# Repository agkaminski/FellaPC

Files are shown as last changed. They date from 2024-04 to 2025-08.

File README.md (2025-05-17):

# FellaPC

All-in-keyboard 6502 based PC with built-in BASIC interpreter.

Features:

- BASIC interpreter,
- 6502/65C02/W65C02S CPU @1.8432 MHz,
- 32 KiB of ROM, 24 KiB of static RAM,
- 640x480@60Hz VGA adapter with character generator (80x60 black and white text mode only),
- 6522 VIA for onboard control, I2C memory and user port,
- 2 UARTs (USB-C and RS-232),
- 68 or 63 button mechanical keyboard,
- edge connector expansion port,
- powered via USB-C port.

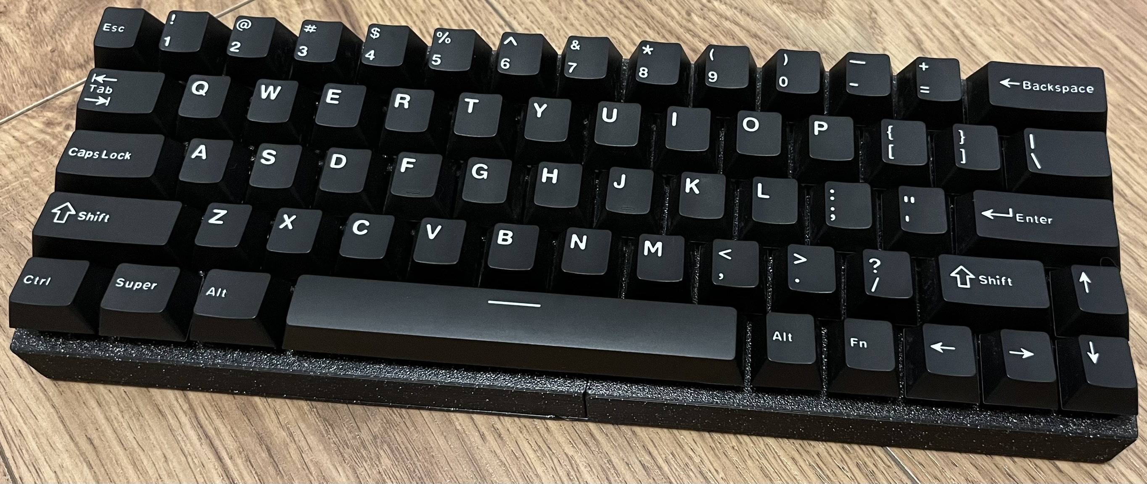
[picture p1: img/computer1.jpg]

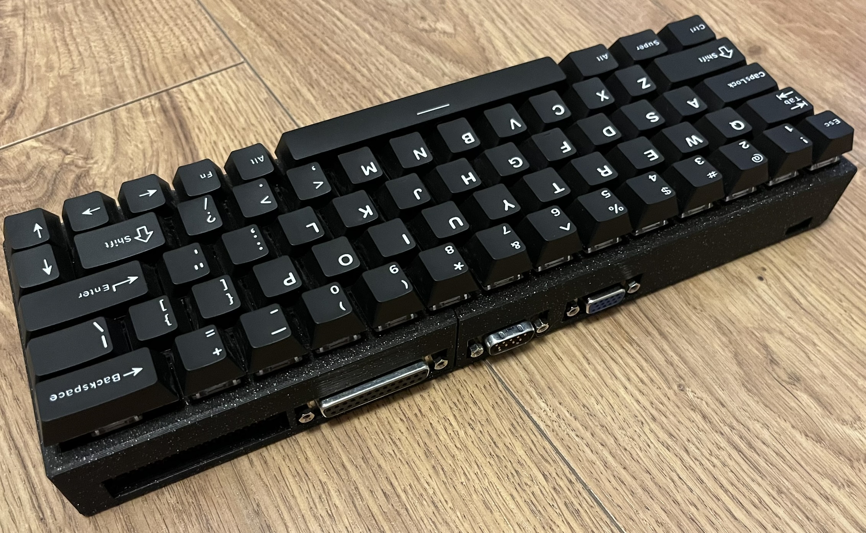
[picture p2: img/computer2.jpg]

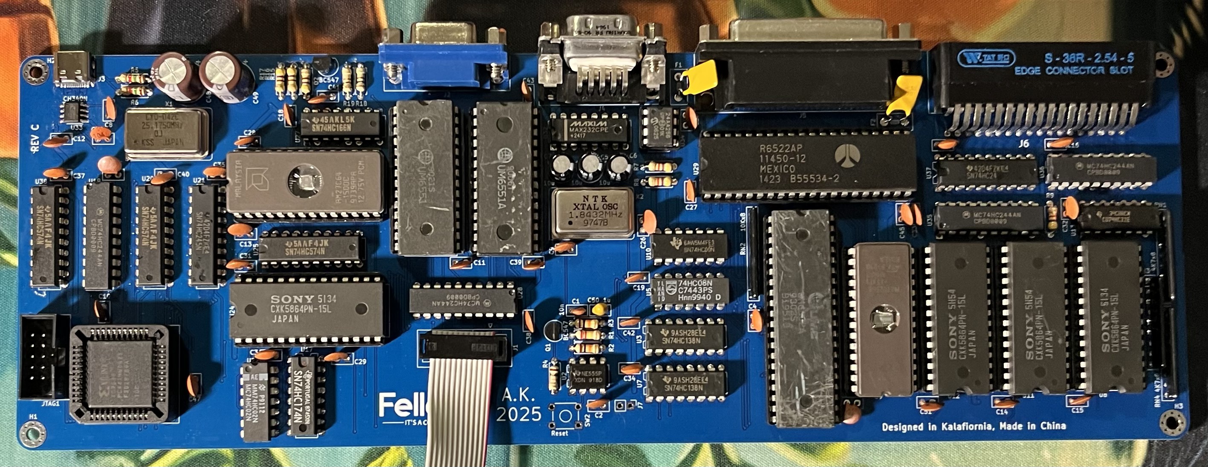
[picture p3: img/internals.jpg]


## Memory map

[Memory map](memmap.md)

## BASIC

FellaPC provides BASIC language subset (partially inspired by C64 BASIC).

### Program editing

Simple line editor is provided, code is entered line by line. To insert a new line or
overwrite existing line type in the line number followed by the code.

Example

```
10 FOR I = 0 TO 10
20 PRINT I
30 NEXT I
```

Let's say we want to change line number 20 to print a square of I insted. To do this
simply type in a new version of this line:

```
20 PRINT I*I
```

The program will be updated:

```
LIST

10 FOR I = 0 TO 10
20 PRINT I*I
30 NEXT I

Ready
```

### Commands

Following commands are supported:

#### PRINT

Print out to the screen.

Syntax examples:

```
PRINT "String"
PRINT "String", variable
PRINT "String"; variable
PRINT variable
PRINT var1, var2
```

#### INPUT

Prompt user for input, real numbers only.

Syntax examples:

```
INPUT var
INPUT "Prompt", var
```

#### FOR, TO, STEP, NEXT

Used for loops. Intelacing and infinite loop nesting are supported.

Syntax example:

```
10 FOR VAR=0 TO 10 STEP 2
20 PRINT I
30 NEXT I
```

Above loop will output:

```
0
2
4
6
8
```

#### GOTO

Jump to the line in the code.

Syntax example:

```
10 GOTO 30
20 PRINT "foo"
30 PRINT "bar"
```

Above code will output only `bar`, as `foo` has been skipped by `goto`.

#### GOSUB, RETURN

Similar to GOTO, but allows returning back from the destination of jump via `RETURN`.
Return address (line after `GOSUB`) is placed on the return stack. There is no limit
on the stack depth (apart from the computer memory capacity).

Syntax example:

```
10 GOSUB 200
20 PRINT "bar"
30 END
200 PRINT "foo"
210 RETURN
```

Folowing code will output:

```
foo
bar
```

#### IF, THEN, ELSE

Conditional execution.

Syntax example:

```
var = 5
10 IF var > 10 THEN 100 ELSE 200
100 PRINT "foo"
200 PRINT "bar"
```

Above code will only output `bar`, as var is not greater than 10.

#### CLEAR

Clear the screen and return cursor to the home position.

#### END

End program execution, return the interactive mode.

#### RUN

Starts execution of the program. Can be used in the interactive mode only.

#### LIST

Displays program. Can be used in the interactive mode only.

#### SAVE

Stores the program on the non-volatile memory. Can be used in the interactive mode only.

#### LOAD

Loads the program from the non-volatile memory. Can be used in the interactive mode only.

#### ABS()

Return absolute value.

Syntax example:

```
10 PRINT ABS(-5)
20 PRINT ABS(5)
```

This program will output:

```
5
5
```

#### FRE

Pseudo-variable. Return available BASIC memory in bytes.

#### INT()

Returns integer part of the real number.

Syntax example

```
PRINT INT(3.1412)
```

Will output `3`.

#### RND

Pseudo-variable. Return a random real number in the range of <0, 1).

#### PEEK(), POKE()

Functions that allow direct reading and modification of the computer memory.

Syntax examples:

```
PRINT PEEK(100)
```

Displays value of the memory at address 100.

```
POKE(100, 42)
```

Stores 42 at the address 100.

#### Operators

Following operators are supported:

```
( ) * + , - / ; < = > <= >= AND NOT OR
```

#### Variables

Variables are declared on the first use:

```
a = 5
var = 42
```

## Limitations

Applies to rev A, rev B:

All limitations in the firmware come from the limited size of the ROM space and
poor performance of the CC65 C compiler. 16 KB of program memory was thought to be
just enought to fit a full BASIC interpreter implementation. Alas, CC65 does not optimize
almost at all for the code size. 6502 is also infamous of not playing nice with the
C language. There was much struggle at the end of the development with the ROM space
running out - so some features were removed or abandoned and some functions has been
rewritten in assembled instead (which provides huge savings). It was deciced against
writing the BASIC interpreter itself in the assembler, in hope to reuse it in the future
project, with its portability in mind. Writing the whole firmware in assembler would also
prolong the project and more it difficult to maintain.

Due to above concerns, following hardware features are not handled by the firmware:

- both UARTs,
- 6522 VIA (apart from I2C and VGA ROM selection),
- interrupts (only NMI/VBLANK is handled).

Although these features can still be used by PEEK and POKE keywords of BASIC.

Visual glitches are expected on the VGA output when the VRAM is being modified. CPU is
too slow and DRAM refresh takes too long to be able to perfom any operation during
VBLANK.

## PCB

FellaPC rev C SBC PCB and keyboard PCB are a 2-layer design.

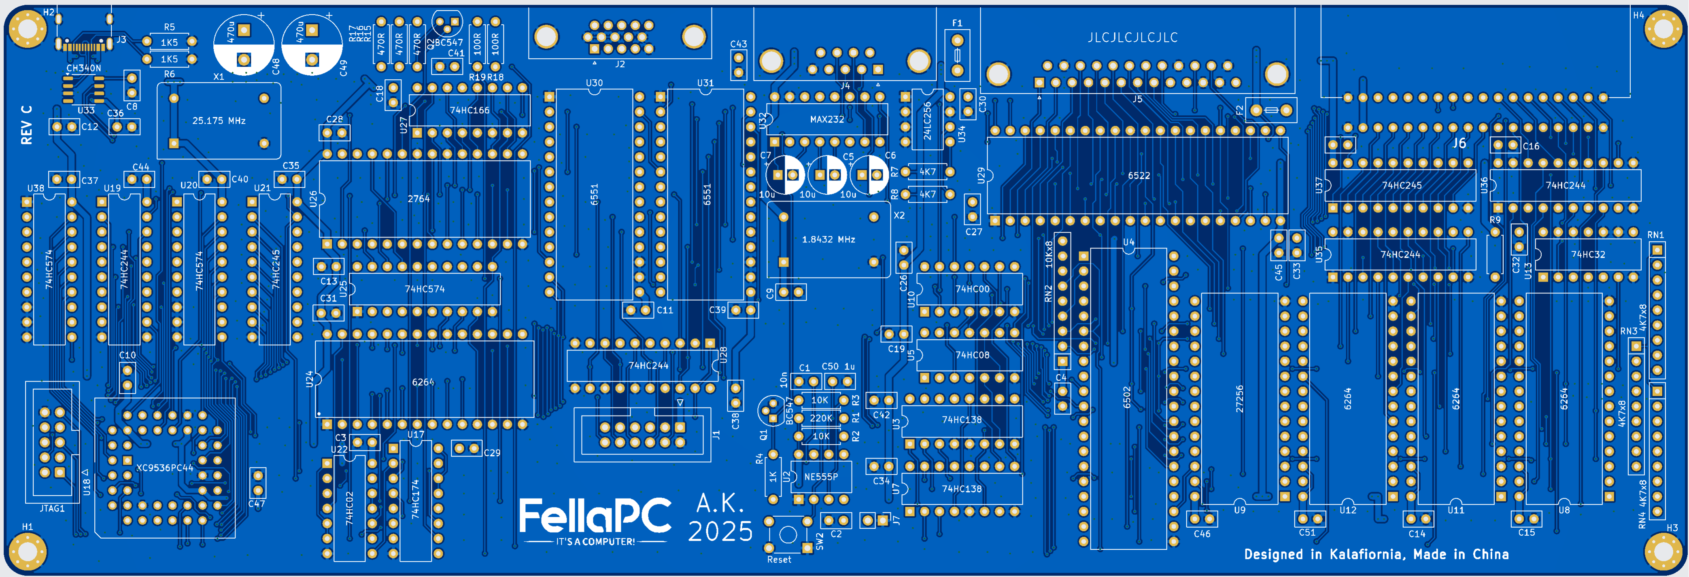
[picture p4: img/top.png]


## Case

Case is provided as STL files that are designed for the FDM 3D priting. There are
three parts:

- keyboard,
- main body,
- bottom panel.

All parts are too big to be printed in one piece on most 3D printers, so cutting
the model during slicing and glueing back together after printing might be needed.
Threaded inserts have to be embedded in the plastic.

Hardware needed:

- threaded inserts:
 - M3 4x5 mm 9 pieces,
 - M3 4x4 mm 4 pieces,
- bolts:
 - M3x4 or M3x5 for keyboard and SCB 8 pieces,
 - M3x25 for main body 5 pieces.

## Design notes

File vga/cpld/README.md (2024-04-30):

# CPLD - VGA timing generator and position counter

Target: XC9536, any speed, **not** XL version

## Pinout

| Pin | Type | Name |
|-----|---|---|
| 1 | I/O | vsync |
| 2 | I/O | hsync |
| 3 | I/O | blank |
| 4 | I/O | shload_n  |
| 5 | I/O/GCK1 | pclk |
| 6 | I/O/GCK2 | TIE |
| 7 | I/O/GCK3 | TIE |
| 8 | I/O | col<9> |
| 9 | I/O | col<8> |
| 10  | GND | GND |
| 11  | I/O | col<7> |
| 12  | I/O | col<6> |
| 13  | I/O | col<5> |
| 14  | I/O | col<4> |
| 15  | TDI | TDI |
| 16  | TMS | TMS |
| 17  | TCK | TCK |
| 18  | I/O | col<3> |
| 19  | I/O | vblank_n  |
| 20  | I/O | scroll<0> |
| 21  | VCCINT | VCC |
| 22  | I/O | scroll<1> |
| 23  | GND | GND |
| 24  | I/O | scroll<4> |
| 25  | I/O | row<8> |
| 26  | I/O | row<7> |
| 27  | I/O | row<6> |
| 28  | I/O | row<5> |
| 29  | I/O | row<4> |
| 30  | TDO | TDO |
| 31  | GND | GND |
| 32  | VCCIO | VCC |
| 33  | I/O | row<3> |
| 34  | I/O | row<2> |
| 35  | I/O | row<1> |
| 36  | I/O | row<0> |
| 37  | I/O | oe_n |
| 38  | I/O | scroll<5> |
| 39  | I/O/GSR  | rst_n |
| 40  | I/O/GTS2 | TIE |
| 41  | VCCINT | VCC |
| 42  | I/O/GTS1 | TIE |
| 43  | I/O | scroll<2> |
| 44  | I/O | scroll<3> |

## vga.v

Implementation

## vga.ucf

Pinout constraints (ISE 14.7)

## vga.jed

Bitstream ready to upload

## tb.v

Sorry excuse for a testbench

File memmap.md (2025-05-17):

# Memory map

| Start  | End | Description |
|---|---|---|
| 0x0000 | 0x5FFF | RAM |
| 0x6000 | 0x7FFF | I/O |
| 0x8000 | 0xFFFF | ROM |

# I/O register map

| Address | Peripheral | Register  | Description |
|---|---|---|---|
| 0x6000  | VGA | VDATA | VGA data (128 registers) |
| 0x6400  | VGA | VRA | VGA row address |
| 0x6800  | VGA | VSCRL | VGA vertical scroll |
| 0x6C00  | Keyboard | COLx | Keyboard columns (0-15) |
| 0x7000  | User port  | ORB | Port B output register |
| 0x7001  | User port  | ORA | Port A output register |
| 0x7002  | User port  | DDRB | Port B direction register |
| 0x7003  | User port  | DDRA | Port A direction register |
| 0x7004  | User port  | T1(L/C)-L | Timer 1 low latch/counter |
| 0x7005  | User port  | T1C-H | Timer 1 high counter |
| 0x7006  | User port  | T1L-L | Timer 1 low latch |
| 0x7007  | User port  | T1L-H | Timer 1 high latch |
| 0x7008  | User port  | T2(L/C)-L | Timer 2 low latch/counter |
| 0x7009  | User port  | T2C-H | Timer 2 high counter |
| 0x700A  | User port  | SR | Shift register |
| 0x700B  | User port  | ACR | Auxiliary control register |
| 0x700C  | User port  | PCR | Peripheral control register  |
| 0x700D  | User port  | IFR | Interrupt flag register |
| 0x700E  | User port  | IER | Interrupt enable register |
| 0x700F  | User port  | ORA | Port A output register |
| 0x7400  | USB UART | TDR1/RDR1 | UART 1 data register |
| 0x7401  | USB UART | RST1/SR1  | UART 1 reset/status register |
| 0x7402  | USB UART | CMDR1 | UART 1 command register |
| 0x7403  | USB UART | CR1 | UART 1 control register |
| 0x7800  | RS232 | TDR2/RDR2 | UART 2 data register |
| 0x7801  | RS232 | RST2/SR2  | UART 2 reset/status register |
| 0x7802  | RS232 | CMDR2 | UART 2 command register |
| 0x7803  | RS232 | CR2 | UART 2 control register |

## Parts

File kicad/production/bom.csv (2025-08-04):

Designator | Footprint | Quantity | Value | LCSC Part #
C1 | C_Disc_D5.0mm_W2.5mm_P2.50mm | 1 | 10n
C10, C11, C12, C13, C14, C15, C16, C17, C18, C19, C2, C26, C27, C28, C29, C3, C30, C31, C32, C33, C34, C35, C36, C37, C38, C39, C4, C40, C41, C42, C43, C44, C45, C46, C47, C51, C8, C9 | C_Disc_D5.0mm_W2.5mm_P2.50mm | 38 | 100n
C48, C49 | CP_Radial_D10.0mm_P5.00mm | 2 | 470u
C5, C6, C7 | CP_Radial_D6.3mm_P2.50mm | 3 | 10u
C50 | C_Disc_D5.0mm_W2.5mm_P2.50mm | 1 | 1u
F1, F2 | Fuse_Littelfuse_395Series | 2 | Fuse
H1, H2, H3, H4 | MountingHole_3.2mm_M3_Pad_Via | 4 | MountingHole_Pad
J1 | IDC-Header_2x06_P2.54mm_Vertical | 1 | Conn_02x06_Odd_Even
J2 | DSUB-15-HD_Female_Horizontal_P2.29x1.98mm_EdgePinOffset3.03mm_Housed_MountingHolesOffset4.94mm | 1 | DE15_Receptacle_HighDensity_MountingHoles
J3 | USB_C_Receptacle_G-Switch_GT-USB-7010ASV | 1 | USB_C_Receptacle_USB2.0_14P
J4 | DSUB-9_Male_Horizontal_P2.77x2.84mm_EdgePinOffset7.70mm_Housed_MountingHolesOffset9.12mm | 1 | DE9_Plug_MountingHoles
J5 | DSUB-25_Socket_Horizontal_P2.77x2.84mm_EdgePinOffset7.70mm_Housed_MountingHolesOffset9.12mm | 1 | DB25_Receptacle_MountingHoles
J6 | EDGE_2x18 | 1 | Conn_02x18_Top_Bottom
J7 | PinHeader_1x02_P2.54mm_Vertical | 1 | Conn_01x02
JTAG1 | IDC-Header_2x05_P2.54mm_Vertical | 1 | Conn_02x05_Odd_Even
Q1, Q2 | TO-92 | 2 | BC547
R1 | R_Axial_DIN0207_L6.3mm_D2.5mm_P7.62mm_Horizontal | 1 | 220K
R15, R16, R17 | R_Axial_DIN0207_L6.3mm_D2.5mm_P7.62mm_Horizontal | 3 | 470R
R18, R19 | R_Axial_DIN0207_L6.3mm_D2.5mm_P7.62mm_Horizontal | 2 | 100R
R2, R3 | R_Axial_DIN0207_L6.3mm_D2.5mm_P7.62mm_Horizontal | 2 | 10K
R4 | R_Axial_DIN0207_L6.3mm_D2.5mm_P7.62mm_Horizontal | 1 | 1K
R5, R6 | R_Axial_DIN0207_L6.3mm_D2.5mm_P7.62mm_Horizontal | 2 | 1K5
R7, R8, R9 | R_Axial_DIN0207_L6.3mm_D2.5mm_P7.62mm_Horizontal | 3 | 4K7
RN1, RN3, RN4 | R_Array_SIP9 | 3 | 4K7x8
RN2 | R_Array_SIP9 | 1 | 10Kx8
SW2 | SW_TH_Tactile_Omron_B3F-10xx | 1 | Reset
U10 | DIP-14_W7.62mm | 1 | 74HC00
U11, U12, U24, U8 | DIP-28_W15.24mm | 4 | 6264
U13 | DIP-14_W7.62mm | 1 | 74HC32
U17 | DIP-16_W7.62mm | 1 | 74HC174
U18 | PLCC-44_THT-Socket | 1 | XC9536PC44
U19, U28, U35, U36 | DIP-20_W7.62mm | 4 | 74HC244
U2 | DIP-8_W7.62mm | 1 | NE555P
U20, U25, U38 | DIP-20_W7.62mm | 3 | 74HC574
U21, U37 | DIP-20_W7.62mm | 2 | 74HC245
U22 | DIP-14_W7.62mm | 1 | 74HC02
U26 | DIP-28_W15.24mm | 1 | 2764
U27 | DIP-16_W7.62mm | 1 | 74HC166
U29 | DIP-40_W15.24mm | 1 | 6522
U3, U7 | DIP-16_W7.62mm | 2 | 74HC138
U30, U31 | DIP-28_W15.24mm | 2 | 6551
U32 | DIP-16_W7.62mm | 1 | MAX232
U33 | SOP-8_3.9x4.9mm_P1.27mm | 1 | CH340N
U34 | DIP-8_W7.62mm | 1 | 24LC256
U4 | DIP-40_W15.24mm | 1 | W65C02SxP
U5 | DIP-14_W7.62mm | 1 | 74HC08
U9 | DIP-28_W15.24mm | 1 | 27256
X1 | Oscillator_DIP-14 | 1 | ACO-25.175MHz-A
X2 | Oscillator_DIP-14 | 1 | ACO-1.8432MHz-A

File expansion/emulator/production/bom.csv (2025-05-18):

Designator | Footprint | Quantity | Value | LCSC Part #
C1, C10, C11, C12, C14, C2, C3, C4, C5, C6, C8, C9 | C_Disc_D3.0mm_W1.6mm_P2.50mm | 12 | 100n
C15, C16 | C_Disc_D3.0mm_W1.6mm_P2.50mm | 2 | 22p
J2 | IDC-Header_2x03_P2.54mm_Vertical | 1 | Conn_02x03_Odd_Even
J3 | USB_C_Receptacle_GCT_USB4105-xx-A_16P_TopMnt_Horizontal | 1 | USB_C_Receptacle_USB2.0_14P
J5 | Expansion Connector | 1 | ~
R1, R4, R5 | R_Axial_DIN0207_L6.3mm_D2.5mm_P7.62mm_Horizontal | 3 | 10K
R2, R3 | R_Axial_DIN0207_L6.3mm_D2.5mm_P7.62mm_Horizontal | 2 | 1K5
U1 | DIP-28_W15.24mm | 1 | CY62256-70PC
U10, U2, U3, U4 | DIP-20_W7.62mm | 4 | 74HC244
U5 | DIP-14_W7.62mm | 1 | 74HC32
U6 | DIP-28_W7.62mm | 1 | ATmega8-16P
U7, U9 | DIP-20_W7.62mm | 2 | 74HC373
U8 | SOP-8_3.9x4.9mm_P1.27mm | 1 | CH340N
Y1 | Crystal_HC49-4H_Vertical | 1 | Crystal

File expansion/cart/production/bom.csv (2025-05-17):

Designator | Footprint | Quantity | Value | LCSC Part #
C1 | C_Disc_D3.4mm_W2.1mm_P2.50mm | 1 | 100n
J1 | PinHeader_1x02_P2.54mm_Vertical | 1 | Conn_01x02
U1 | CART_FELLA_38 | 1 | ~
U2 | DIP-28_W15.24mm | 1 | 27256

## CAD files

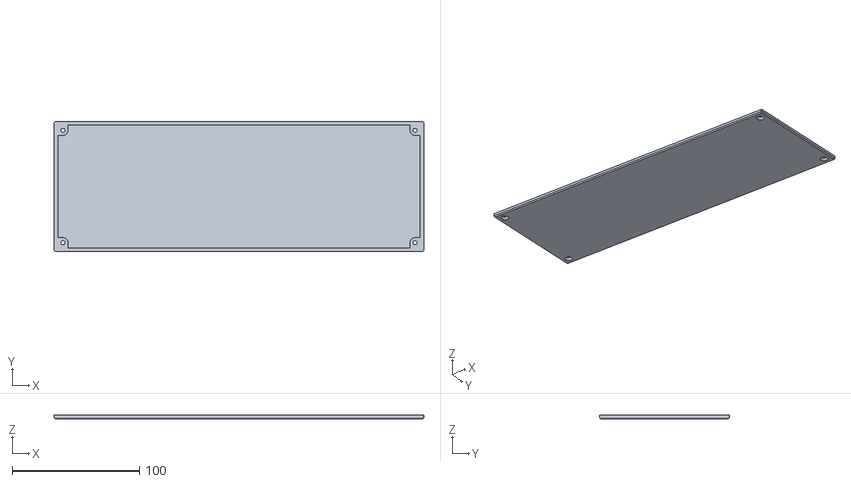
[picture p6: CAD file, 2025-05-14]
mechanical/mini-Bottom.stl
290.9 x 102.5 x 3.00

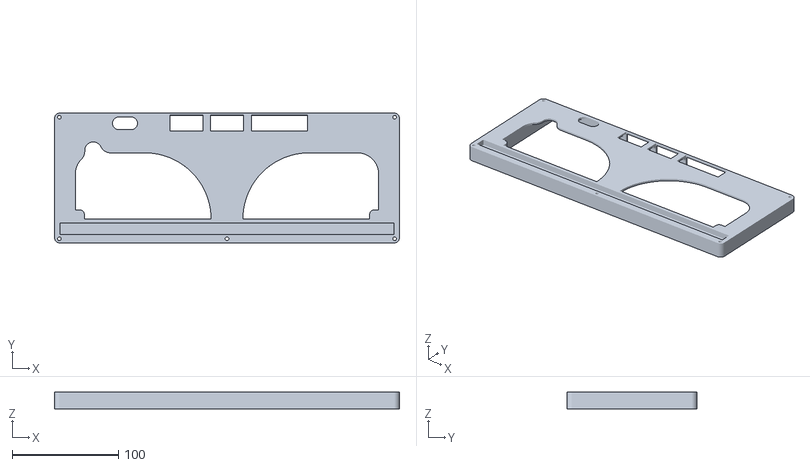
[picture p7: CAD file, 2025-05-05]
mechanical/body.stl
325.0 x 122.4 x 16.0

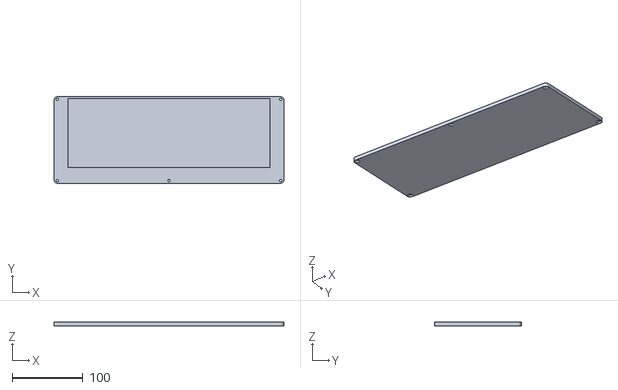
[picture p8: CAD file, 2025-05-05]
mechanical/bottom.stl
325.0 x 122.4 x 5.00

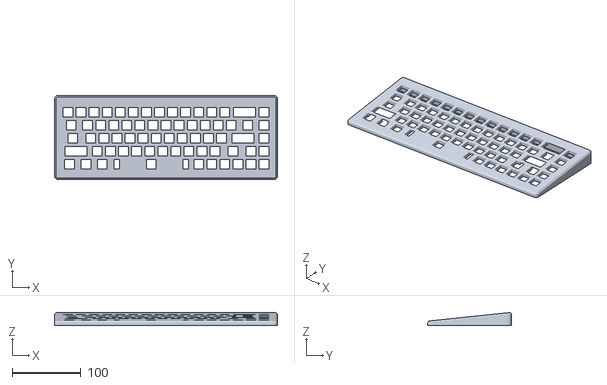
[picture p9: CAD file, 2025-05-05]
mechanical/keyboard.stl
325.0 x 122.4 x 18.9

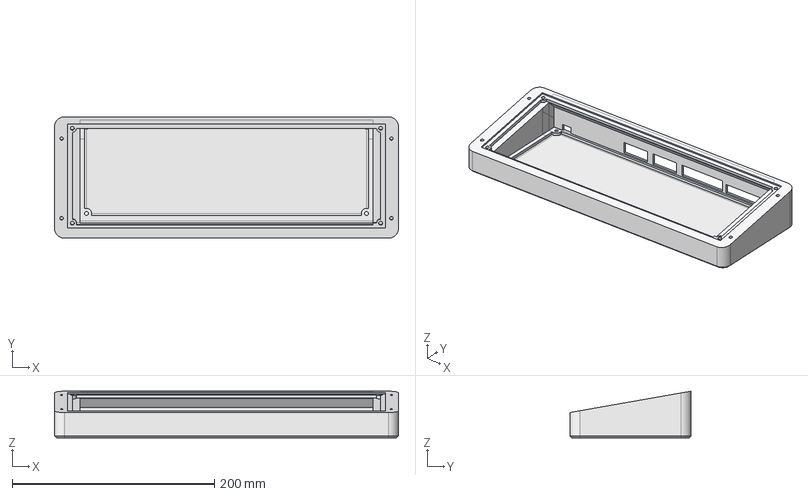
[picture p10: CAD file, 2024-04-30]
mechanical/case.FCStd
340.0 x 120.0 x 46.2 mm

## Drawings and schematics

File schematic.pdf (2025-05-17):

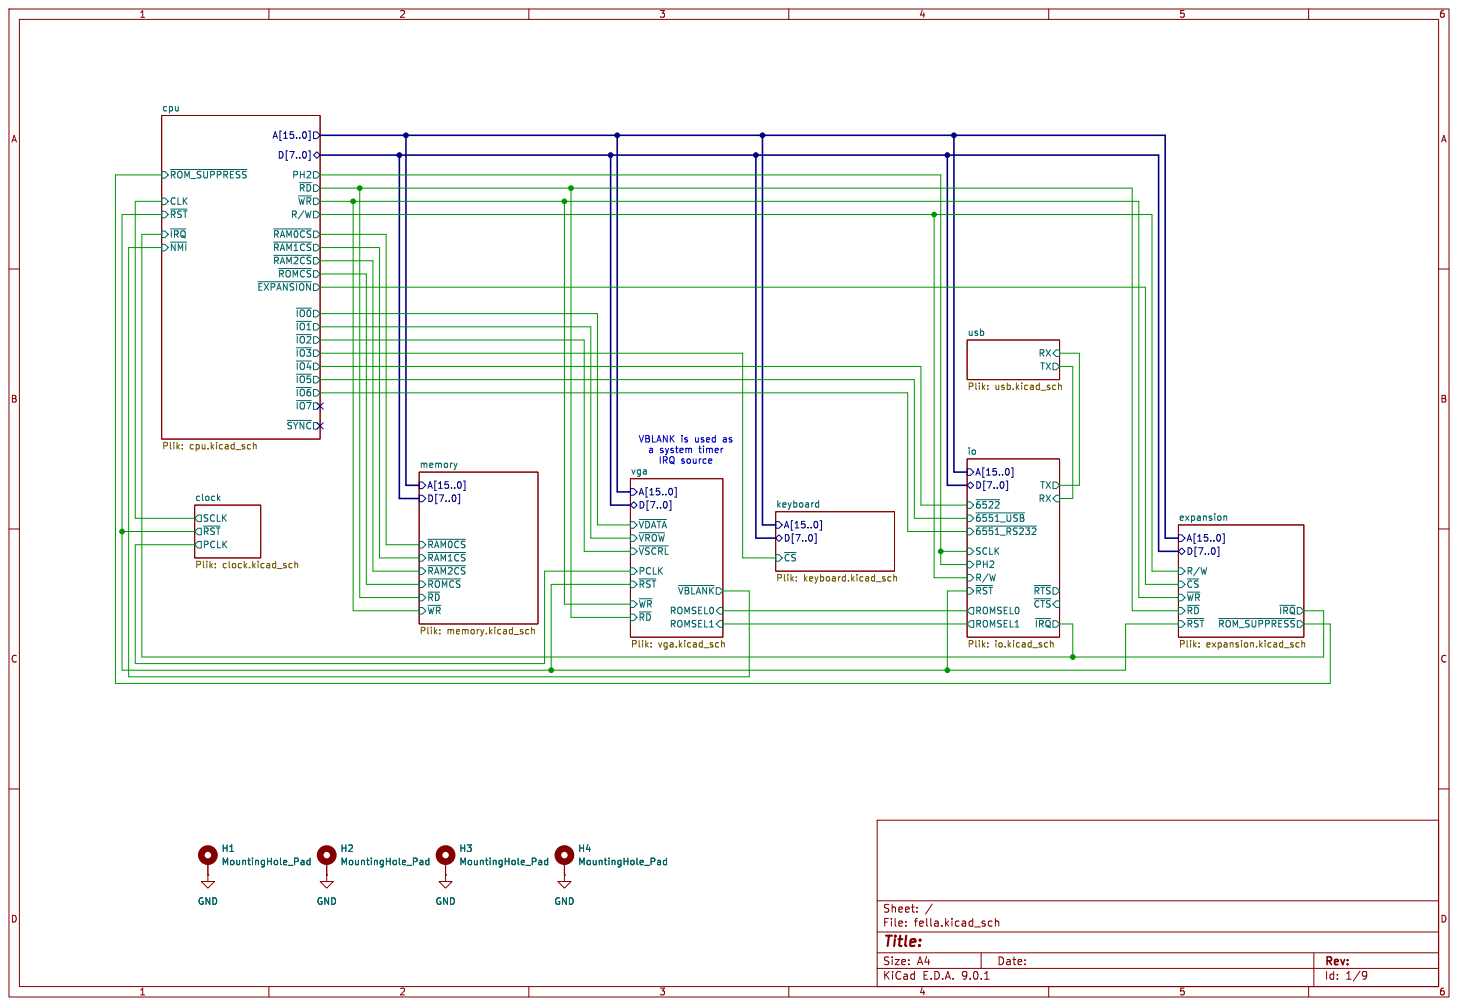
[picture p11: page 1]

usb Plik: usb.kicad_sch ~{RST} PCLK
~{VSCRL} vga Plik: vga.kicad_sch

~{ROMCS} memory Plik: memory.kicad_sch PCLK

keyboard Plik: keyboard.kicad_sch
Id: 1/9 Title: File: fella.kicad_sch Sheet: / A[15..0]

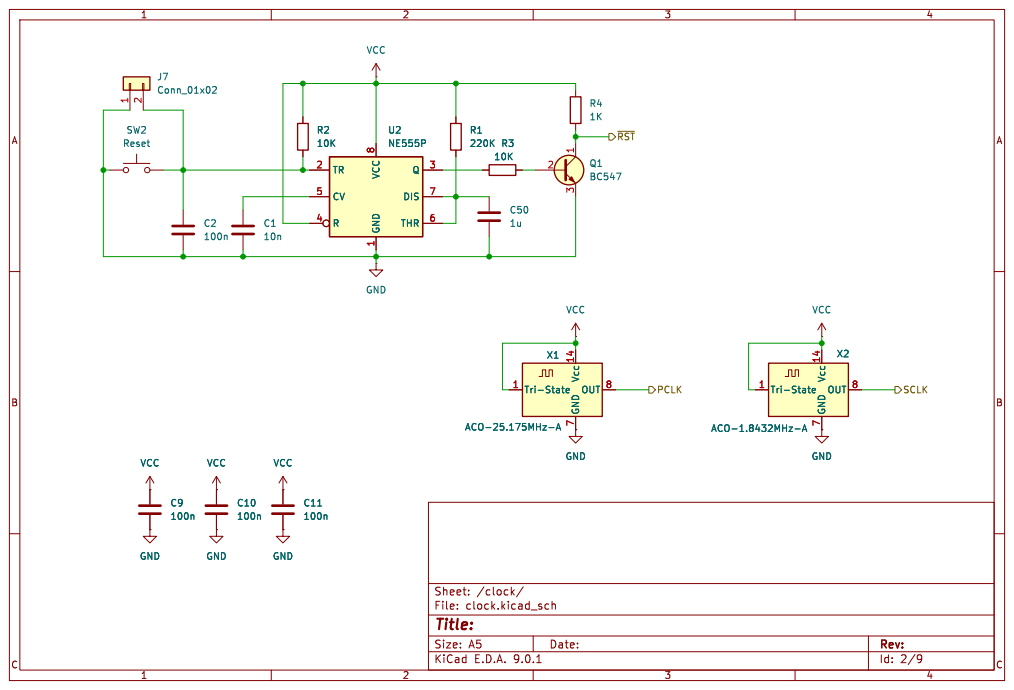
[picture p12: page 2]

Id: 2/9 Title: File: clock.kicad_sch Sheet: /clock/ VCC

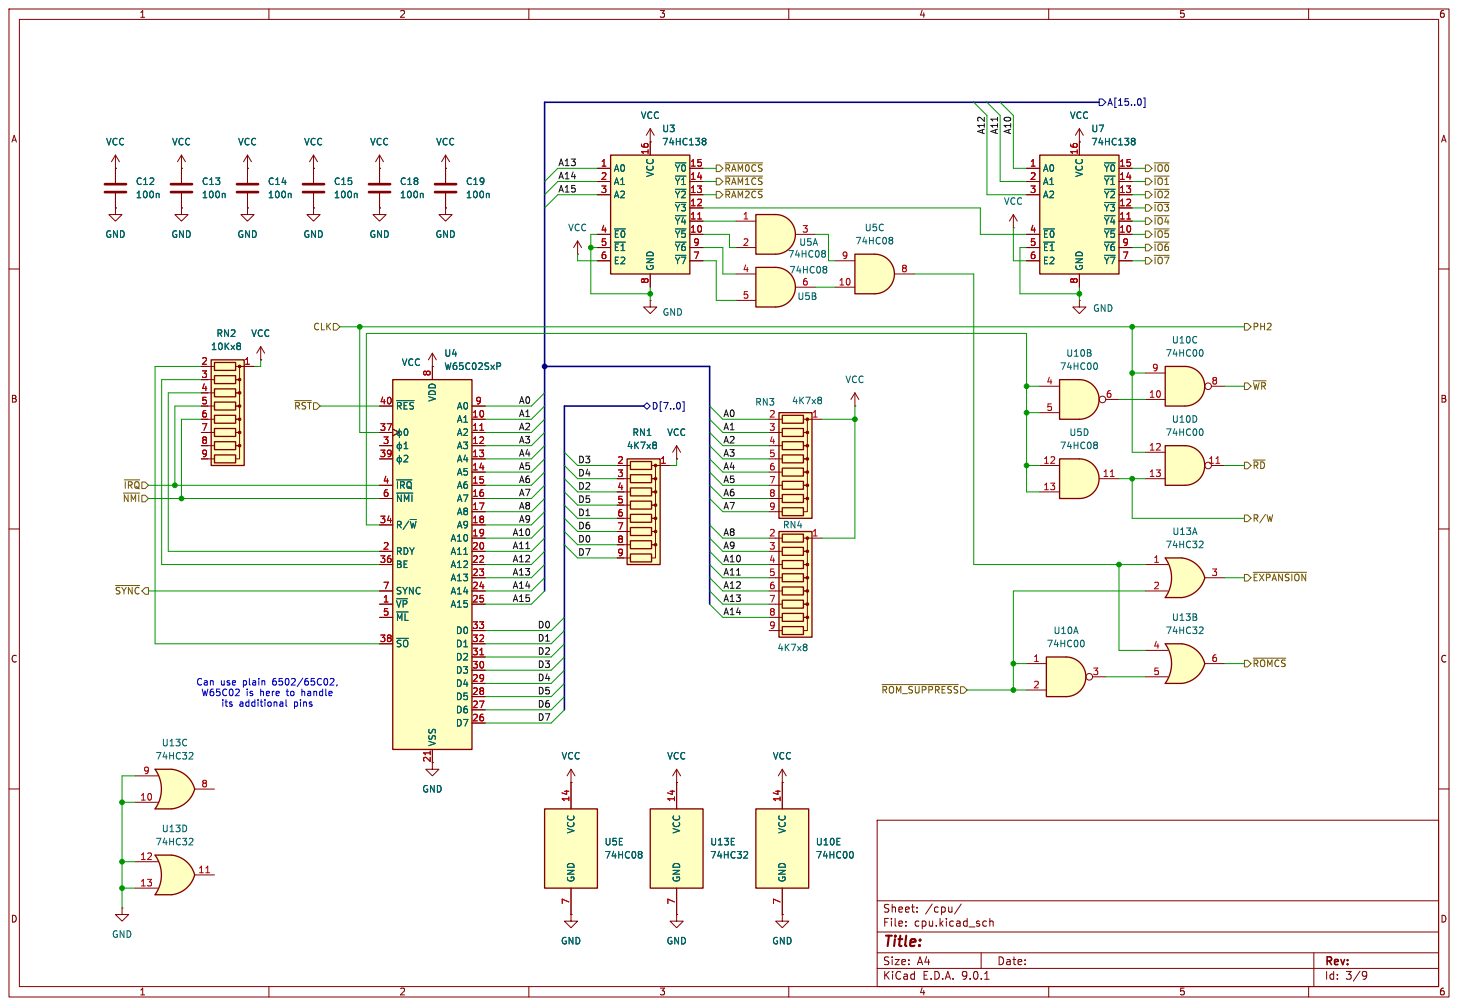
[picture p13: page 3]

A15 D5 Can use plain 6502/65C02, W65C02 is here to handle

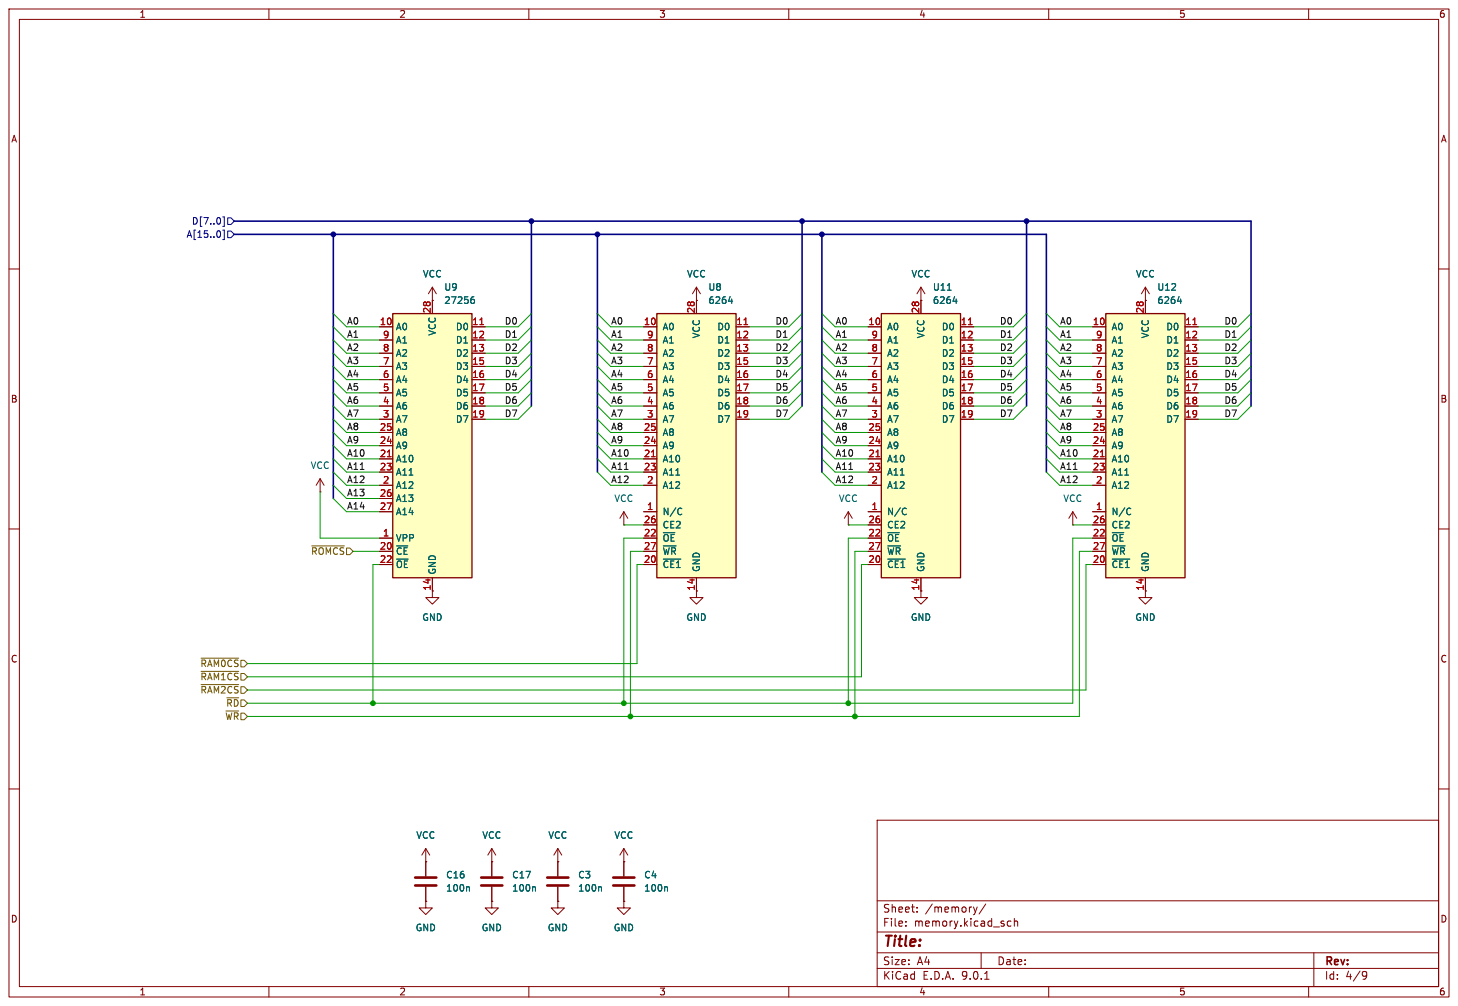
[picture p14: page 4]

Id: 4/9 Title: File: memory.kicad_sch Sheet: /memory/

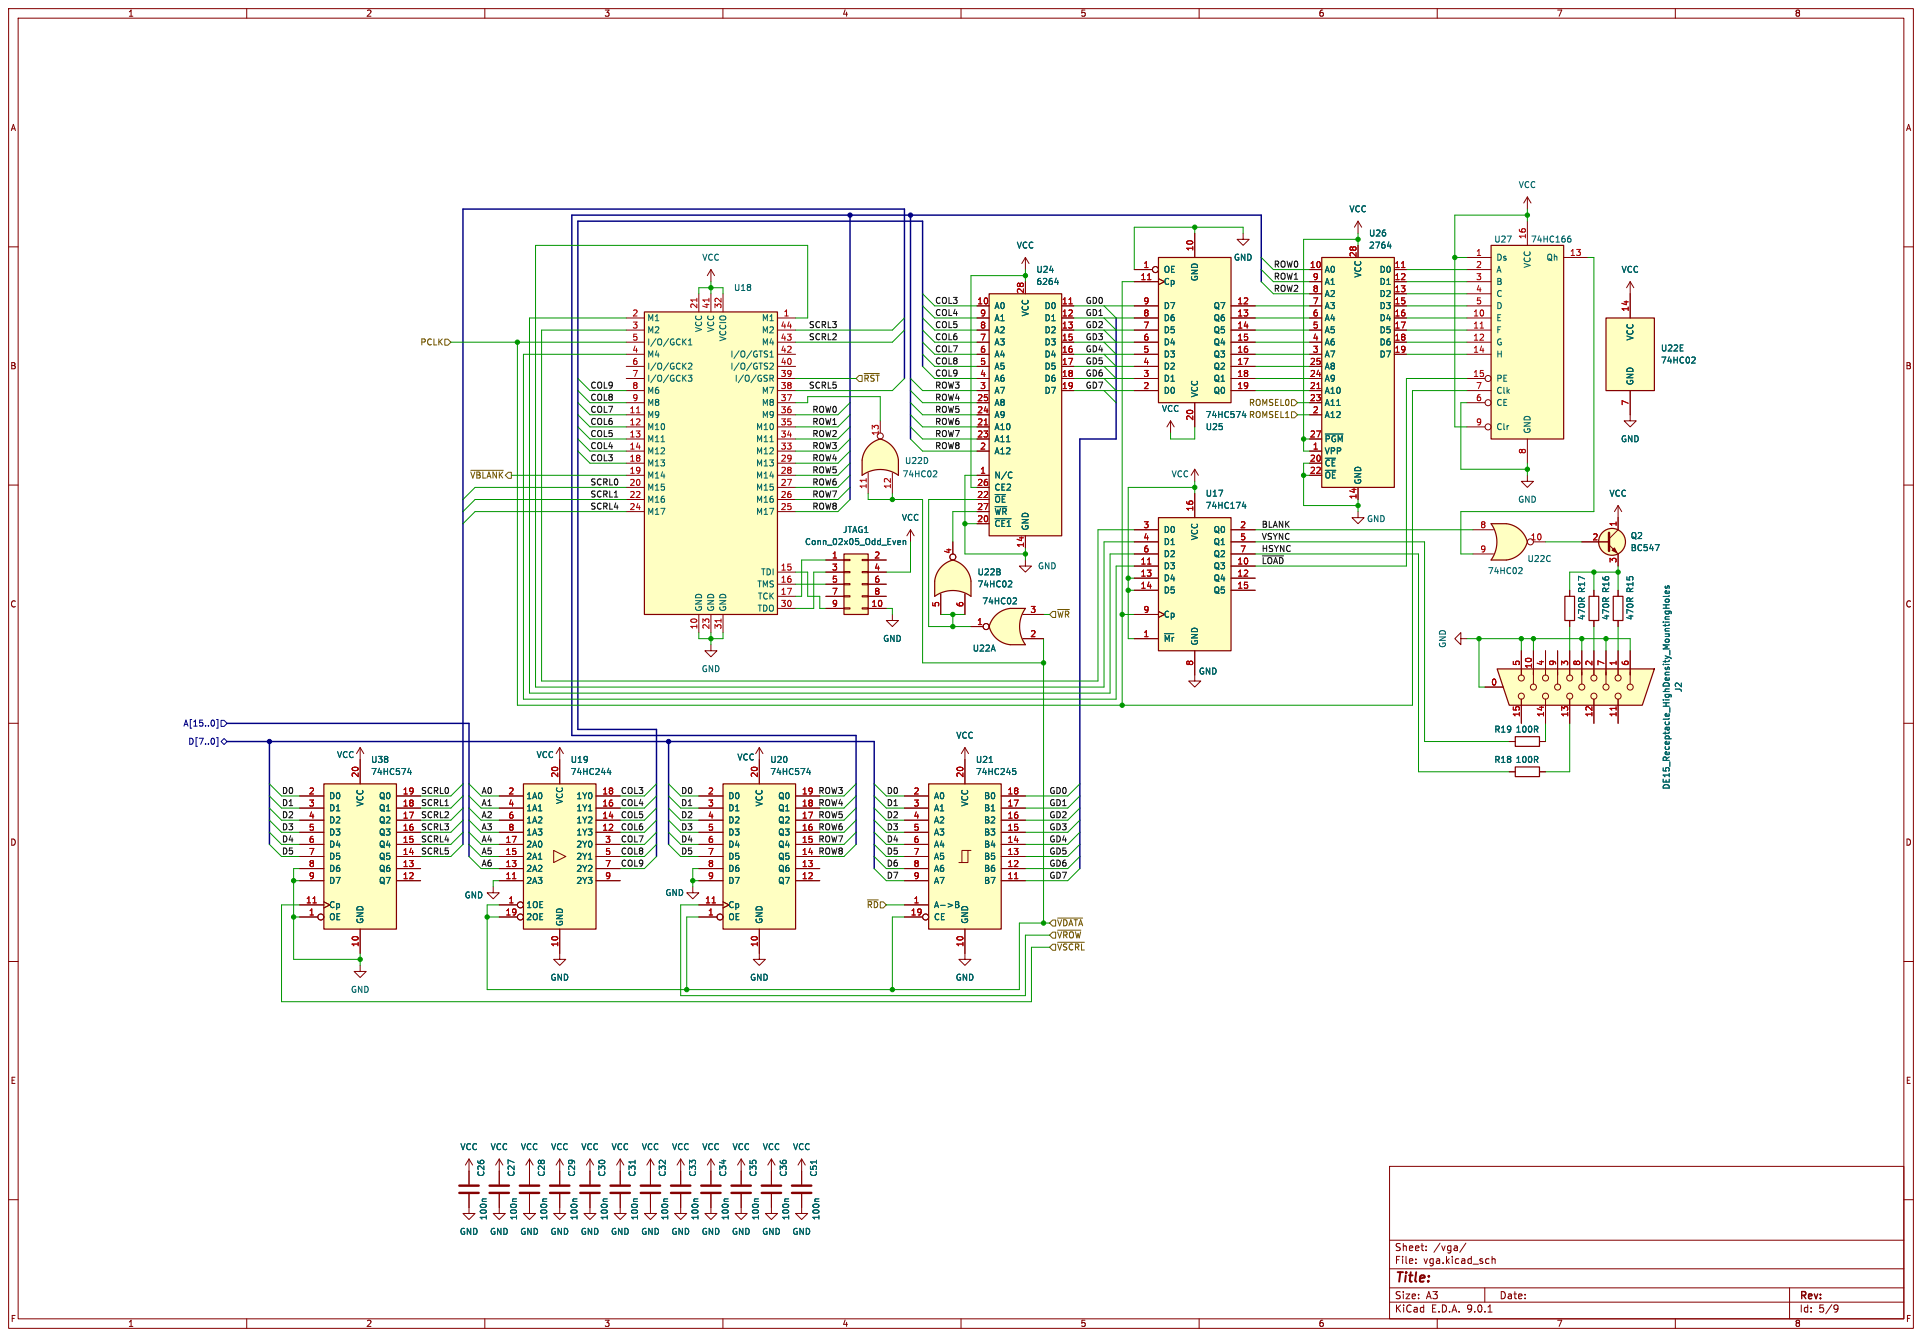
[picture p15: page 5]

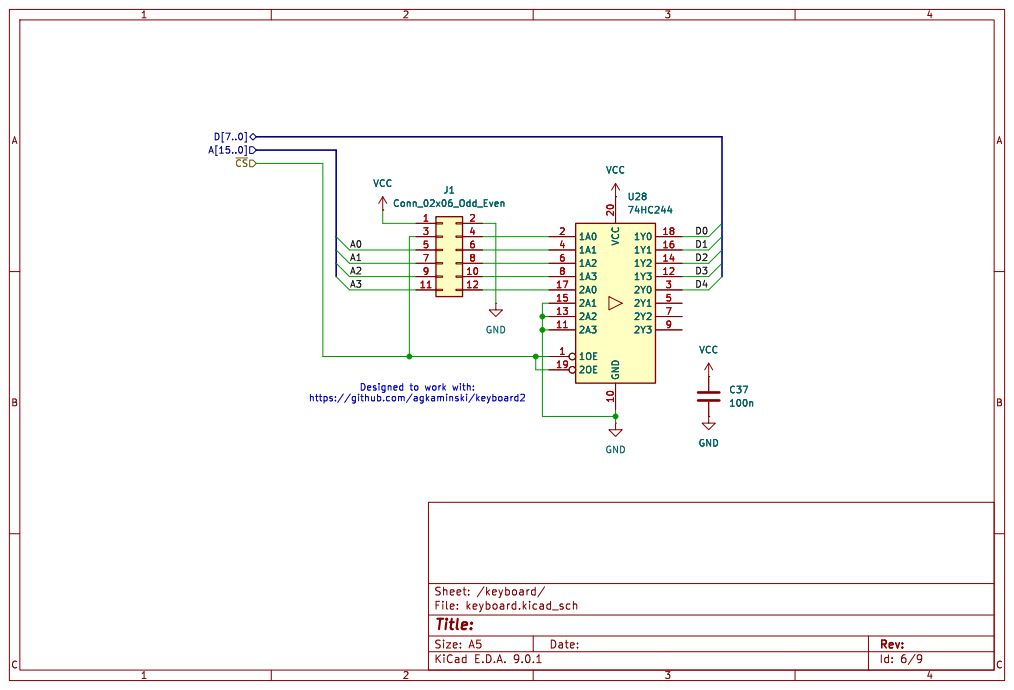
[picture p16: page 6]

10 10 | 1A3 8
12 | 2A0 17

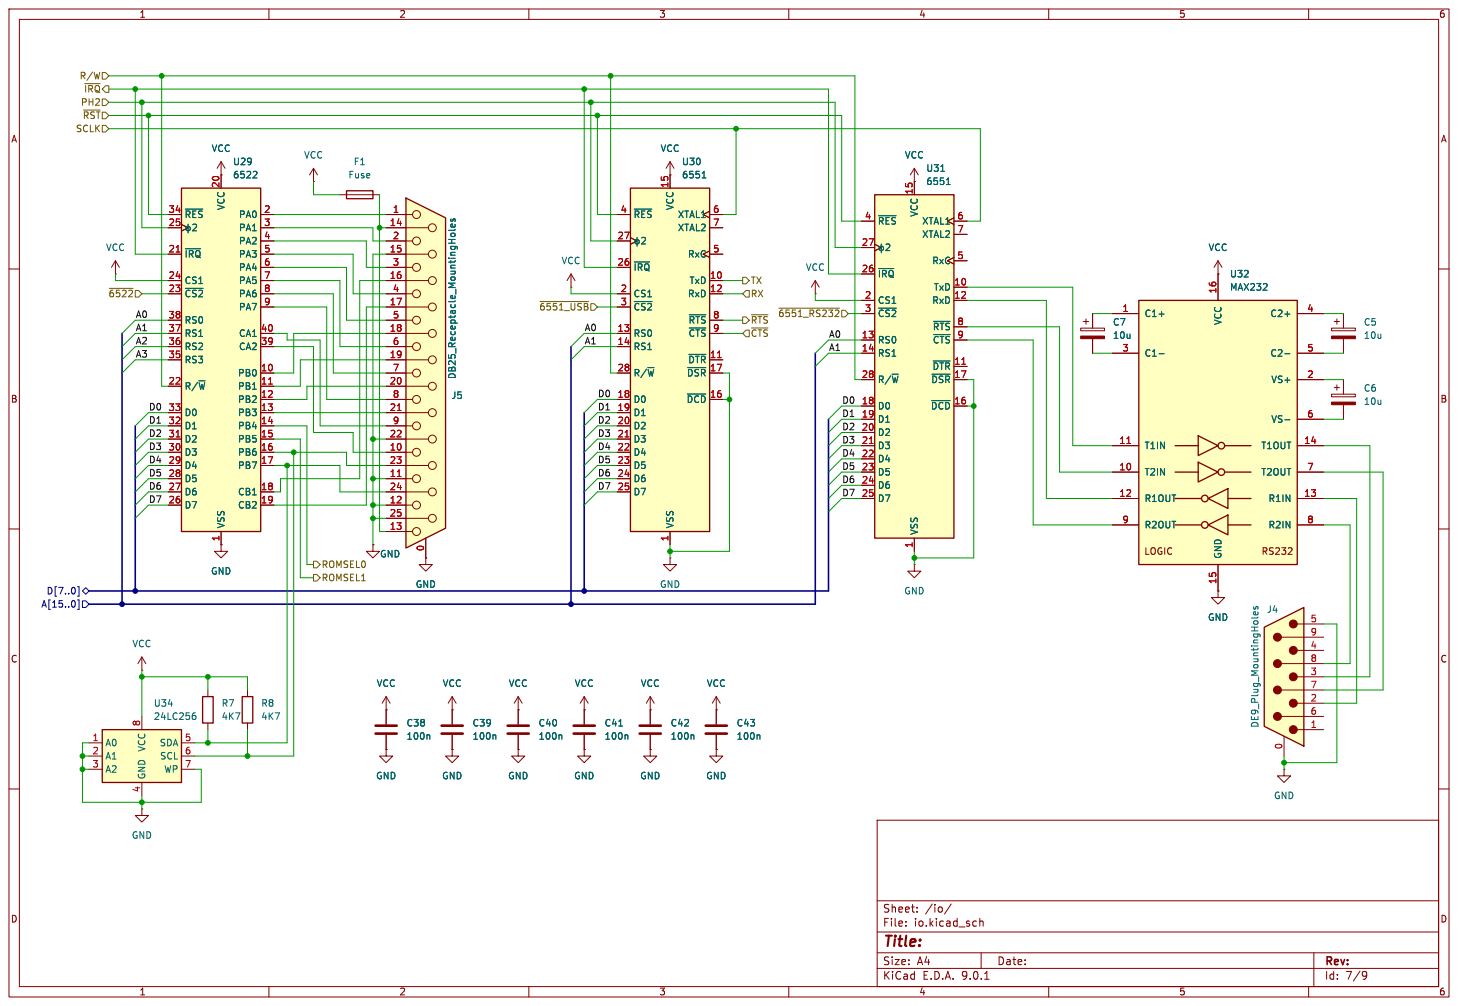
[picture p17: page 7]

Id: 7/9 Title: File: io.kicad_sch Sheet: /io/

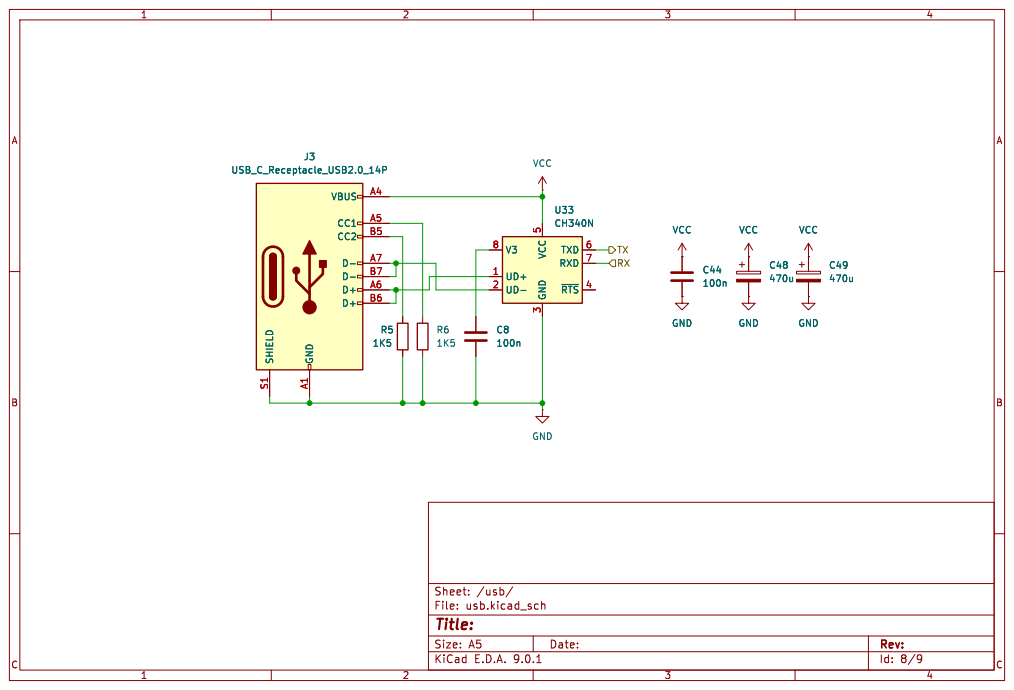
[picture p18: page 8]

3 TXD 6 RXD 7 ~{RTS}4 U33 CH340N GND

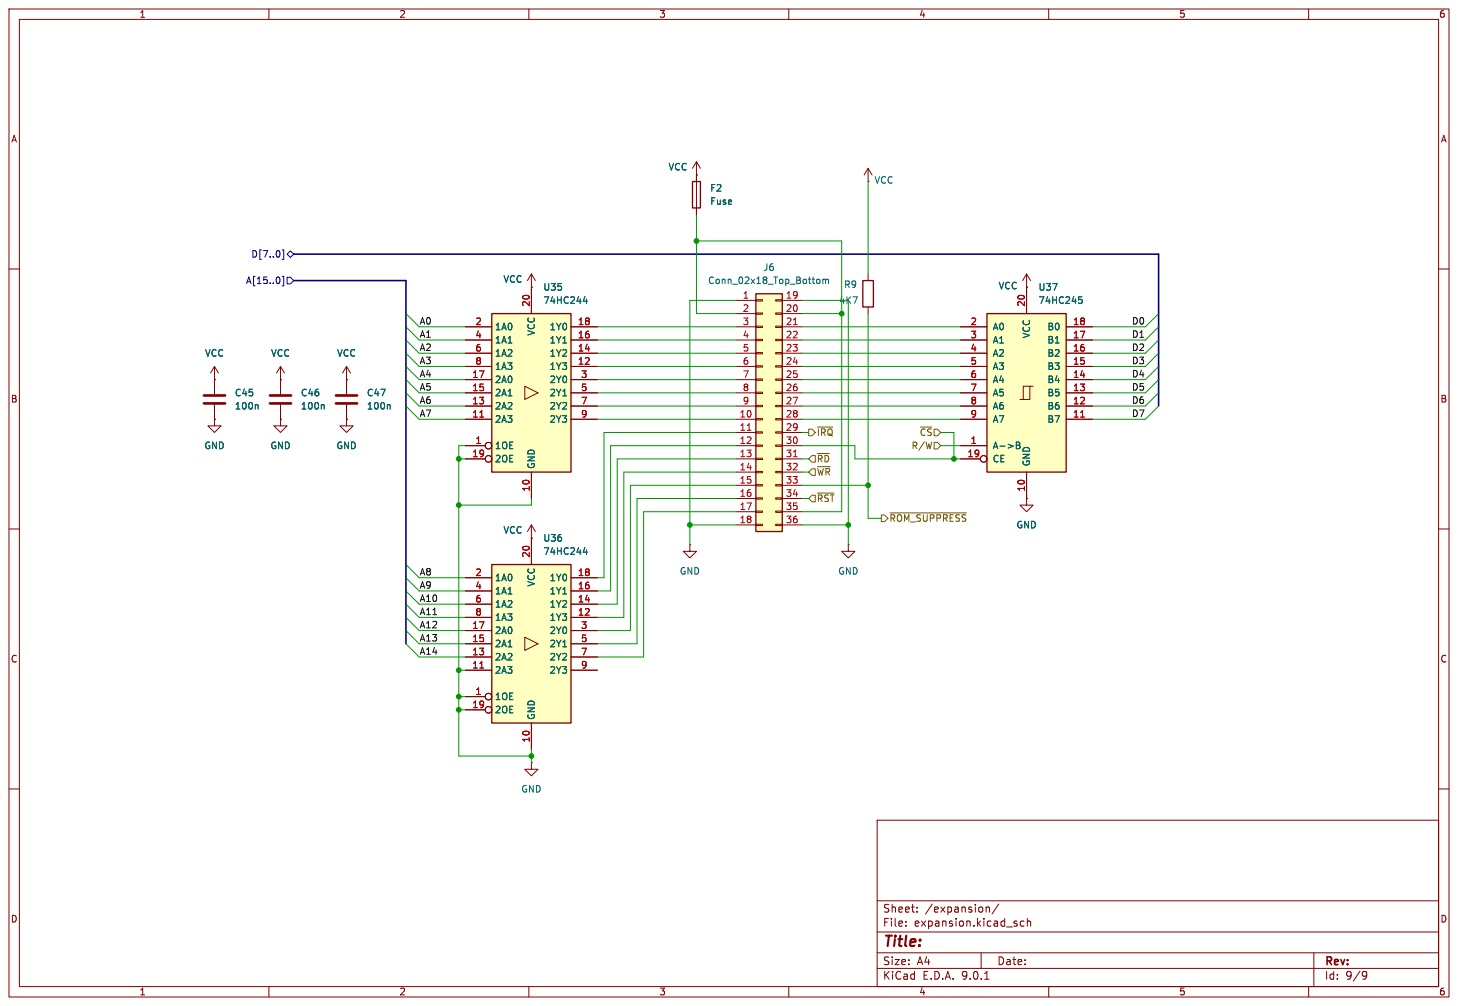
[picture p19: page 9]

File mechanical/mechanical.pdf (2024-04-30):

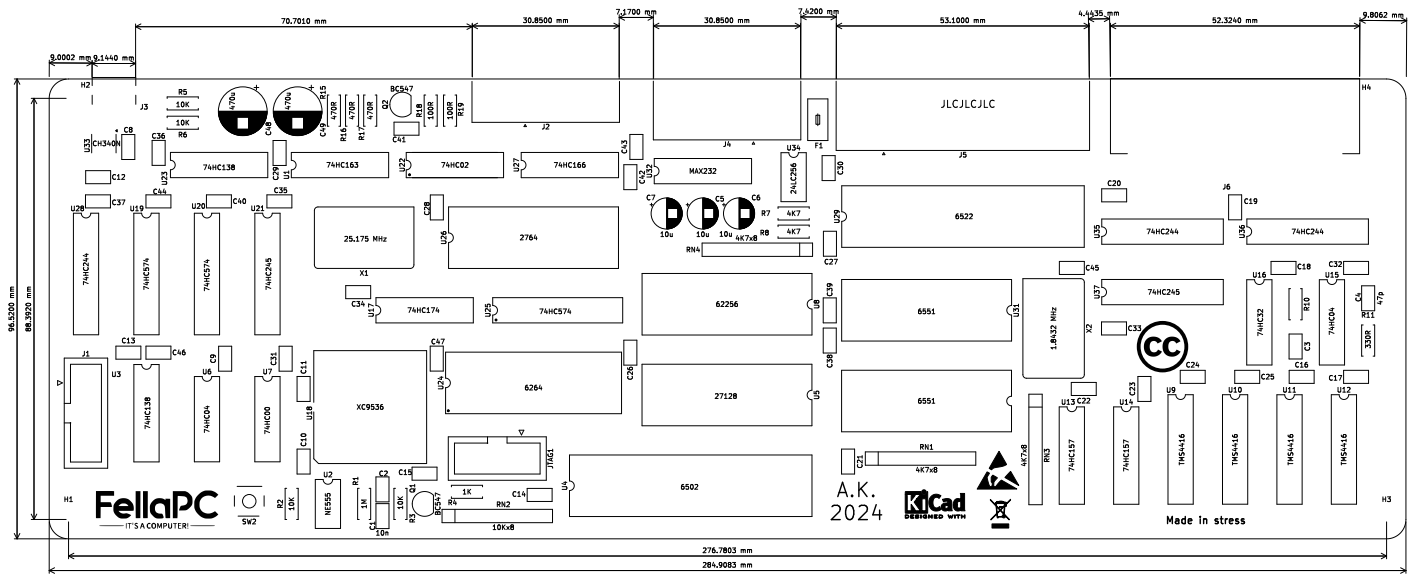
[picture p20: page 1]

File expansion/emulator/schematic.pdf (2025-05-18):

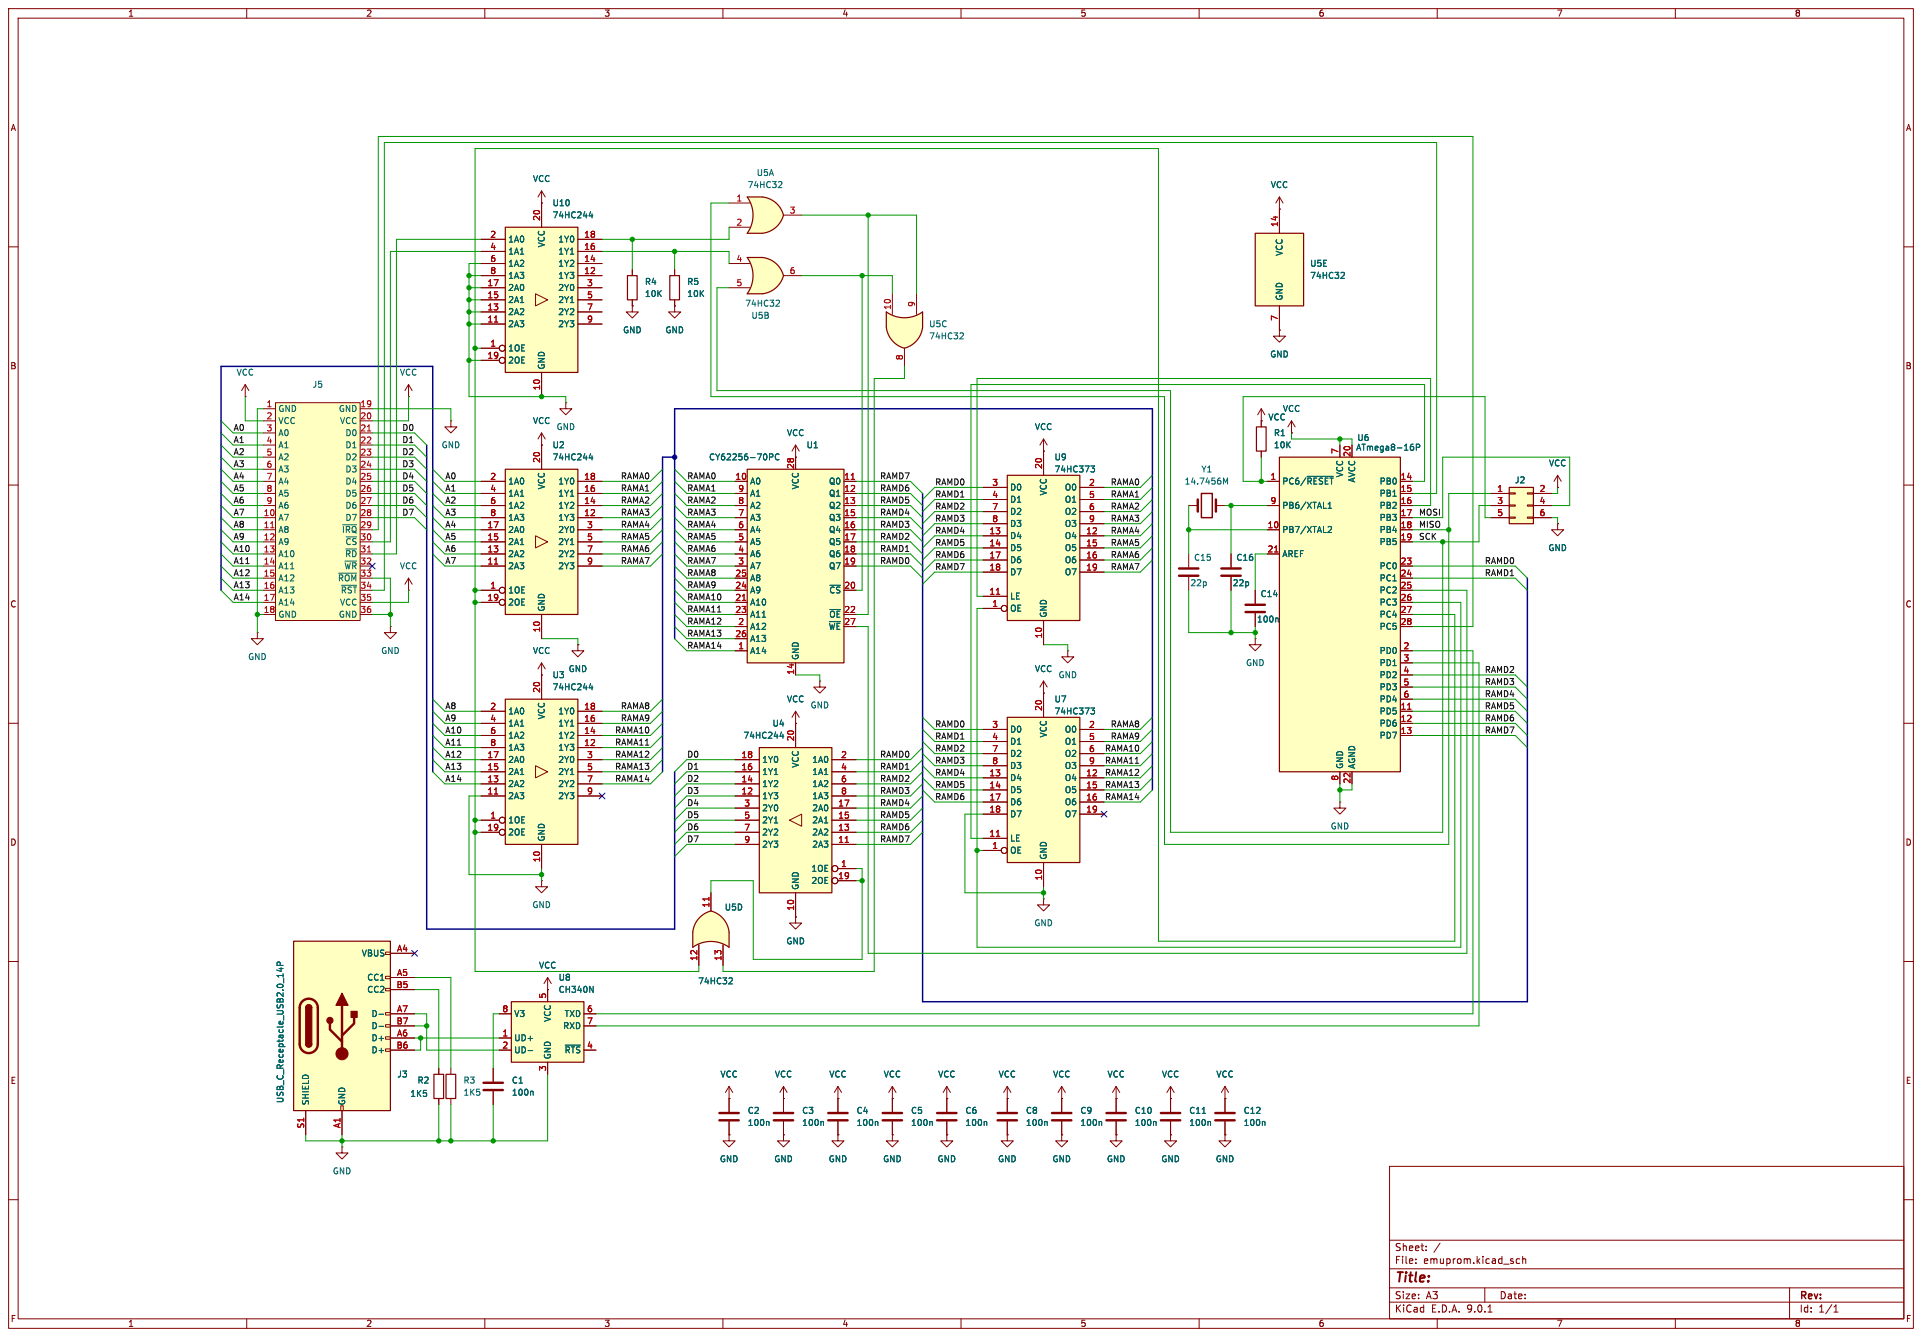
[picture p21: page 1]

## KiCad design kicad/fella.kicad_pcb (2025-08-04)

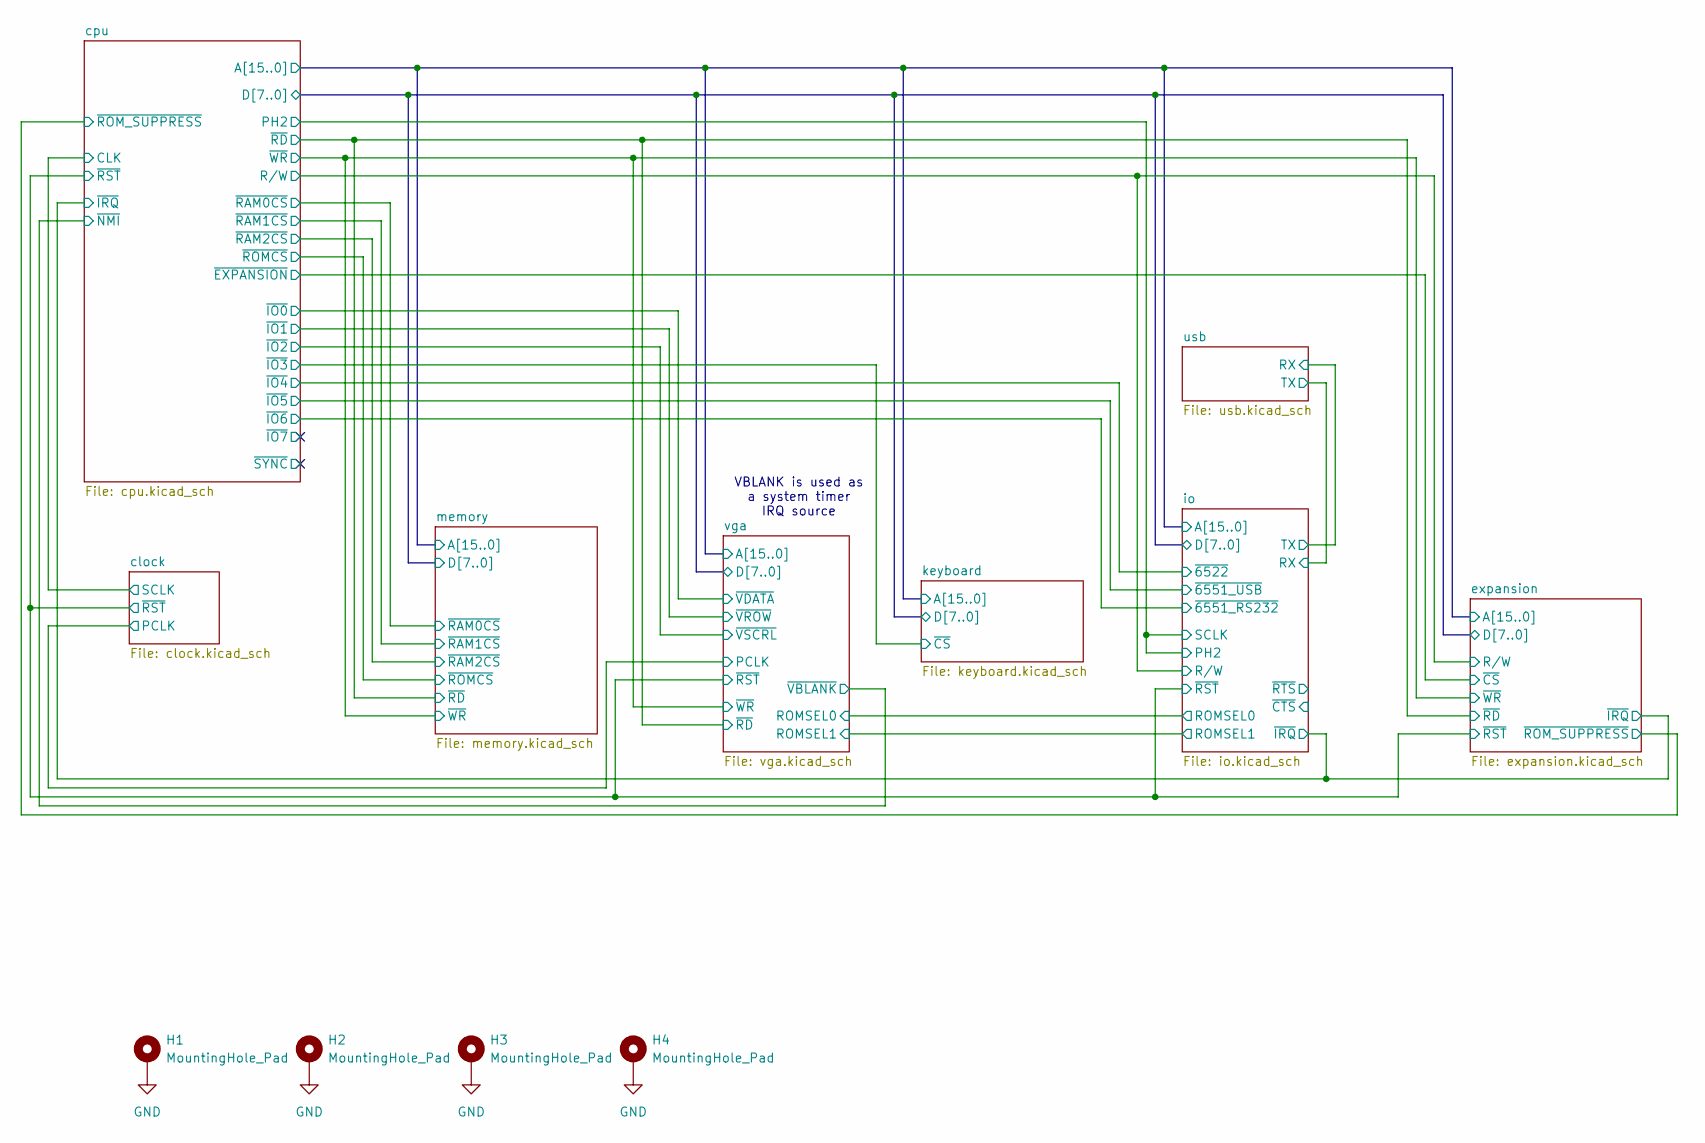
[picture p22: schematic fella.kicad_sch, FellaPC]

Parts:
H1, H2, H3, H4: MountingHole_Pad; MountingHole_3.2mm_M3_Pad_Via

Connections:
GND: H1.1, H2.1, H3.1, H4.1; also elsewhere on the board

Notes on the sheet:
VBLANK is used as a system timer IRQ source

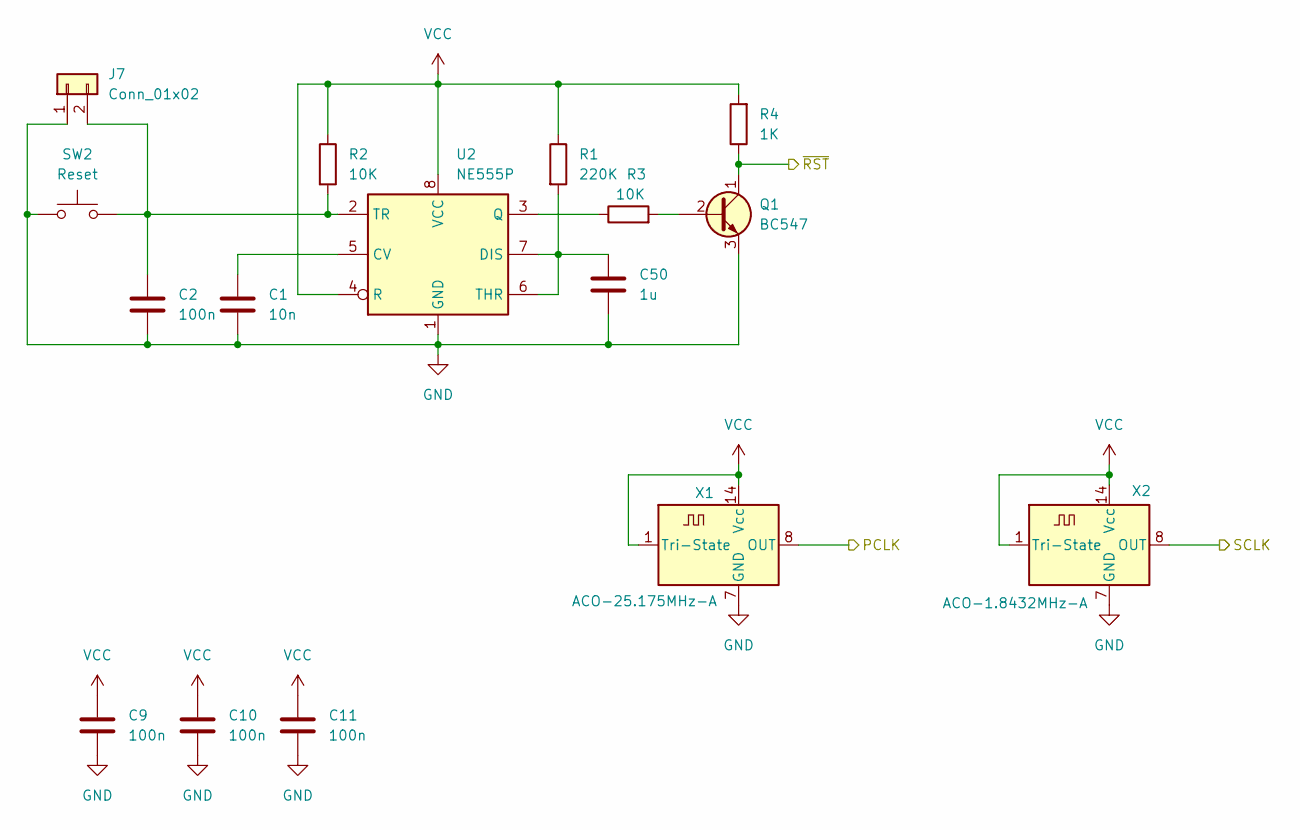
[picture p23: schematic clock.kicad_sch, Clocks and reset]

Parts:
C1: 10n; C_Disc_D5.0mm_W2.5mm_P2.50mm
C2, C9, C10, C11: 100n; C_Disc_D5.0mm_W2.5mm_P2.50mm
C50: 1u; C_Disc_D5.0mm_W2.5mm_P2.50mm
J7: Conn_01x02; PinHeader_1x02_P2.54mm_Vertical
Q1: BC547; TO-92
R1: 220K; R_Axial_DIN0207_L6.3mm_D2.5mm_P7.62mm_Horizontal
R2, R3: 10K; R_Axial_DIN0207_L6.3mm_D2.5mm_P7.62mm_Horizontal
R4: 1K; R_Axial_DIN0207_L6.3mm_D2.5mm_P7.62mm_Horizontal
SW2: Reset; SW_TH_Tactile_Omron_B3F-10xx
U2: NE555P; DIP-8_W7.62mm
X1: ACO-25.175MHz-A; Oscillator_DIP-14
X2: ACO-1.8432MHz-A; Oscillator_DIP-14

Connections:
/clock/PCLK: X1.8 (OUT); also elsewhere on the board
/clock/SCLK: X2.8 (OUT); also elsewhere on the board
/clock/~RST: Q1.1 (C), R4.1; also elsewhere on the board
GND: C1.2, C2.2, C9.2, C10.2, C11.2, C50.2, J7.1, Q1.3 (E), SW2.1, U2.1 (GND), X1.7 (GND), X2.7 (GND); also elsewhere on the board
unnamed: C2.1, J7.2, R2.2, SW2.2, U2.2 (TR)
unnamed: Q1.2 (B), R3.2
unnamed: C1.1, U2.5 (CV)
unnamed: C50.1, R1.2, U2.6 (THR), U2.7 (DIS)
unnamed: R3.1, U2.3 (Q)
VCC: C9.1, C10.1, C11.1, R1.1, R2.1, R4.2, U2.4 (R), U2.8 (VCC), X1.1 (Tri-State), X1.14 (Vcc), X2.1 (Tri-State), X2.14 (Vcc); also elsewhere on the board

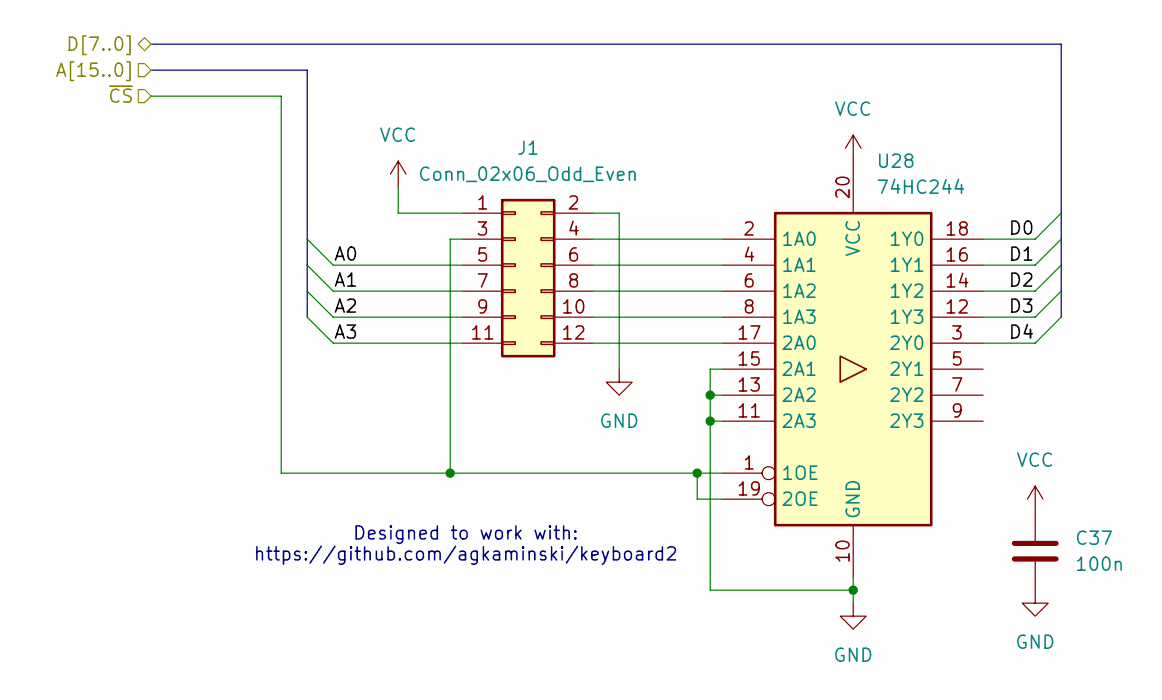
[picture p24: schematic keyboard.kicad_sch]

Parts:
C37: 100n; C_Disc_D5.0mm_W2.5mm_P2.50mm
J1: Conn_02x06_Odd_Even; IDC-Header_2x06_P2.54mm_Vertical
U28: 74HC244; DIP-20_W7.62mm

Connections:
/cpu/A0: J1.5; also elsewhere on the board
/cpu/A1: J1.7; also elsewhere on the board
/cpu/A2: J1.9; also elsewhere on the board
/cpu/A3: J1.11; also elsewhere on the board
/cpu/D0: U28.18 (1Y0); also elsewhere on the board
/cpu/D1: U28.16 (1Y1); also elsewhere on the board
/cpu/D2: U28.14 (1Y2); also elsewhere on the board
/cpu/D3: U28.12 (1Y3); also elsewhere on the board
/cpu/D4: U28.3 (2Y0); also elsewhere on the board
/cpu/~IO3: J1.3, U28.1 (1OE), U28.19 (2OE); also elsewhere on the board
GND: C37.2, J1.2, U28.10 (GND), U28.11 (2A3), U28.13 (2A2), U28.15 (2A1); also elsewhere on the board
unnamed: J1.4, U28.2 (1A0)
unnamed: J1.6, U28.4 (1A1)
unnamed: J1.8, U28.6 (1A2)
unnamed: J1.10, U28.8 (1A3)
unnamed: J1.12, U28.17 (2A0)
VCC: C37.1, J1.1, U28.20 (VCC); also elsewhere on the board

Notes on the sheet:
Designed to work with: https://github.com/agkaminski/keyboard2

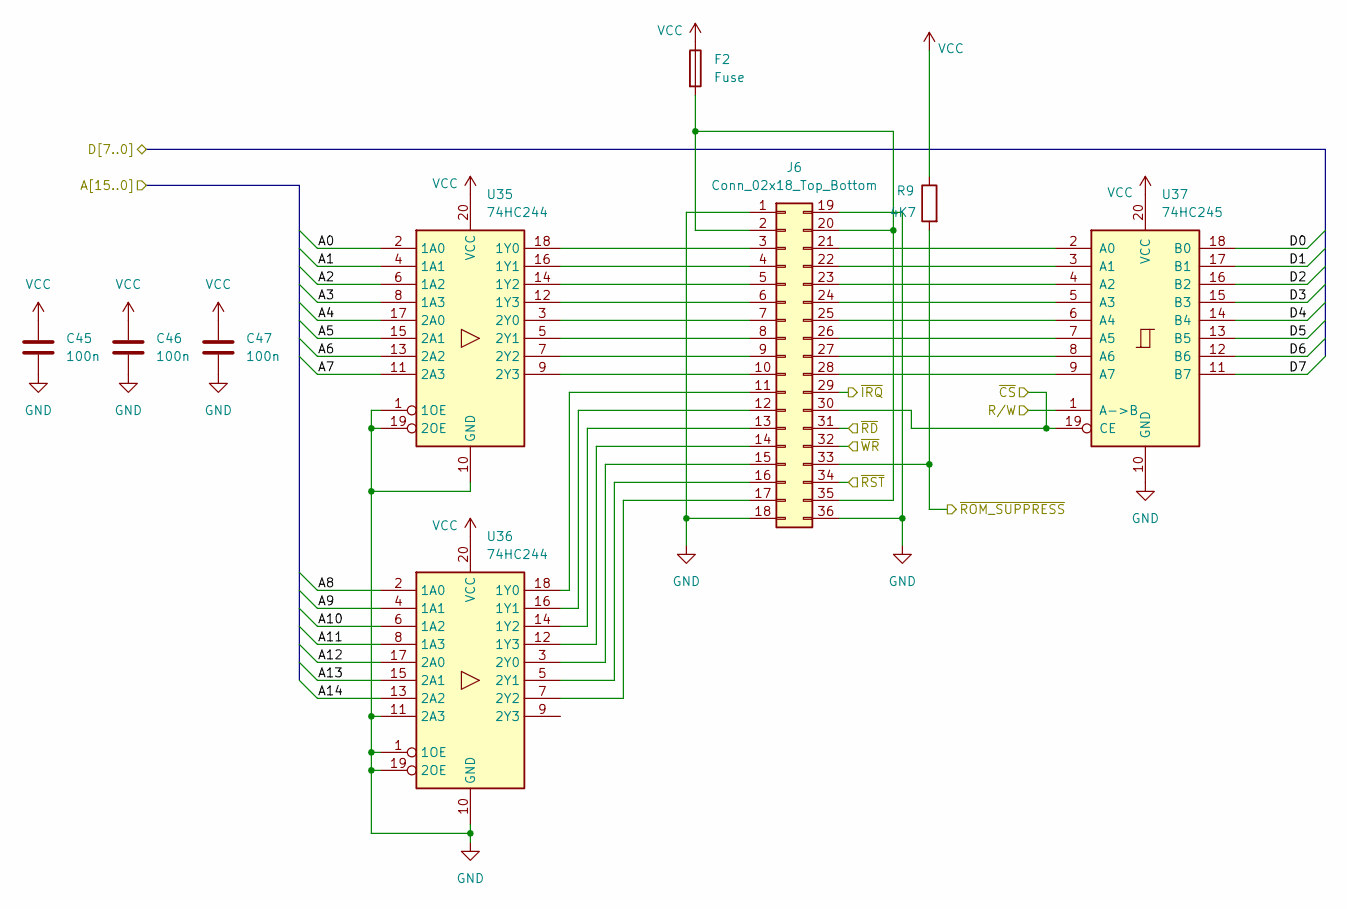
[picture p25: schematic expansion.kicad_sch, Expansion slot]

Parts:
C45, C46, C47: 100n; C_Disc_D5.0mm_W2.5mm_P2.50mm
F2: Fuse; Fuse_Littelfuse_395Series
J6: Conn_02x18_Top_Bottom; EDGE_2x18
R9: 4K7; R_Axial_DIN0207_L6.3mm_D2.5mm_P7.62mm_Horizontal
U35, U36: 74HC244; DIP-20_W7.62mm
U37: 74HC245; DIP-20_W7.62mm

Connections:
/clock/~RST: J6.34; also elsewhere on the board
/cpu/A0: U35.2 (1A0); also elsewhere on the board
/cpu/A1: U35.4 (1A1); also elsewhere on the board
/cpu/A2: U35.6 (1A2); also elsewhere on the board
/cpu/A3: U35.8 (1A3); also elsewhere on the board
/cpu/A4: U35.17 (2A0); also elsewhere on the board
/cpu/A5: U35.15 (2A1); also elsewhere on the board
/cpu/A6: U35.13 (2A2); also elsewhere on the board
/cpu/A7: U35.11 (2A3); also elsewhere on the board
/cpu/A8: U36.2 (1A0); also elsewhere on the board
/cpu/A9: U36.4 (1A1); also elsewhere on the board
/cpu/A10: U36.6 (1A2); also elsewhere on the board
/cpu/A11: U36.8 (1A3); also elsewhere on the board
/cpu/A12: U36.17 (2A0); also elsewhere on the board
/cpu/A13: U36.15 (2A1); also elsewhere on the board
/cpu/A14: U36.13 (2A2); also elsewhere on the board
/cpu/D0: U37.18 (B0); also elsewhere on the board
/cpu/D1: U37.17 (B1); also elsewhere on the board
/cpu/D2: U37.16 (B2); also elsewhere on the board
/cpu/D3: U37.15 (B3); also elsewhere on the board
/cpu/D4: U37.14 (B4); also elsewhere on the board
/cpu/D5: U37.13 (B5); also elsewhere on the board
/cpu/D6: U37.12 (B6); also elsewhere on the board
/cpu/D7: U37.11 (B7); also elsewhere on the board
/cpu/R/W: U37.1 (A->B); also elsewhere on the board
/cpu/~EXPANSION: J6.30, U37.19 (CE); also elsewhere on the board
/cpu/~IRQ: J6.29; also elsewhere on the board
/cpu/~RD: J6.31; also elsewhere on the board
/cpu/~ROM_SUPPRESS: J6.33, R9.2; also elsewhere on the board
/cpu/~WR: J6.32; also elsewhere on the board
GND: C45.2, C46.2, C47.2, J6.1, J6.18, J6.19, J6.36, U35.1 (1OE), U35.10 (GND), U35.19 (2OE), U36.1 (1OE), U36.10 (GND), U36.11 (2A3), U36.19 (2OE), U37.10 (GND); also elsewhere on the board
unnamed: F2.2, J6.2, J6.20, J6.35
unnamed: J6.3, U35.18 (1Y0)
unnamed: J6.4, U35.16 (1Y1)
unnamed: J6.5, U35.14 (1Y2)
unnamed: J6.6, U35.12 (1Y3)
unnamed: J6.7, U35.3 (2Y0)
unnamed: J6.8, U35.5 (2Y1)
unnamed: J6.9, U35.7 (2Y2)
unnamed: J6.10, U35.9 (2Y3)
unnamed: J6.11, U36.18 (1Y0)
unnamed: J6.12, U36.16 (1Y1)
unnamed: J6.13, U36.14 (1Y2)
unnamed: J6.14, U36.12 (1Y3)
unnamed: J6.15, U36.3 (2Y0)
unnamed: J6.16, U36.5 (2Y1)
unnamed: J6.17, U36.7 (2Y2)
unnamed: J6.21, U37.2 (A0)
unnamed: J6.22, U37.3 (A1)
unnamed: J6.23, U37.4 (A2)
unnamed: J6.24, U37.5 (A3)
unnamed: J6.25, U37.6 (A4)
unnamed: J6.26, U37.7 (A5)
unnamed: J6.27, U37.8 (A6)
unnamed: J6.28, U37.9 (A7)
VCC: C45.1, C46.1, C47.1, F2.1, R9.1, U35.20 (VCC), U36.20 (VCC), U37.20 (VCC); also elsewhere on the board

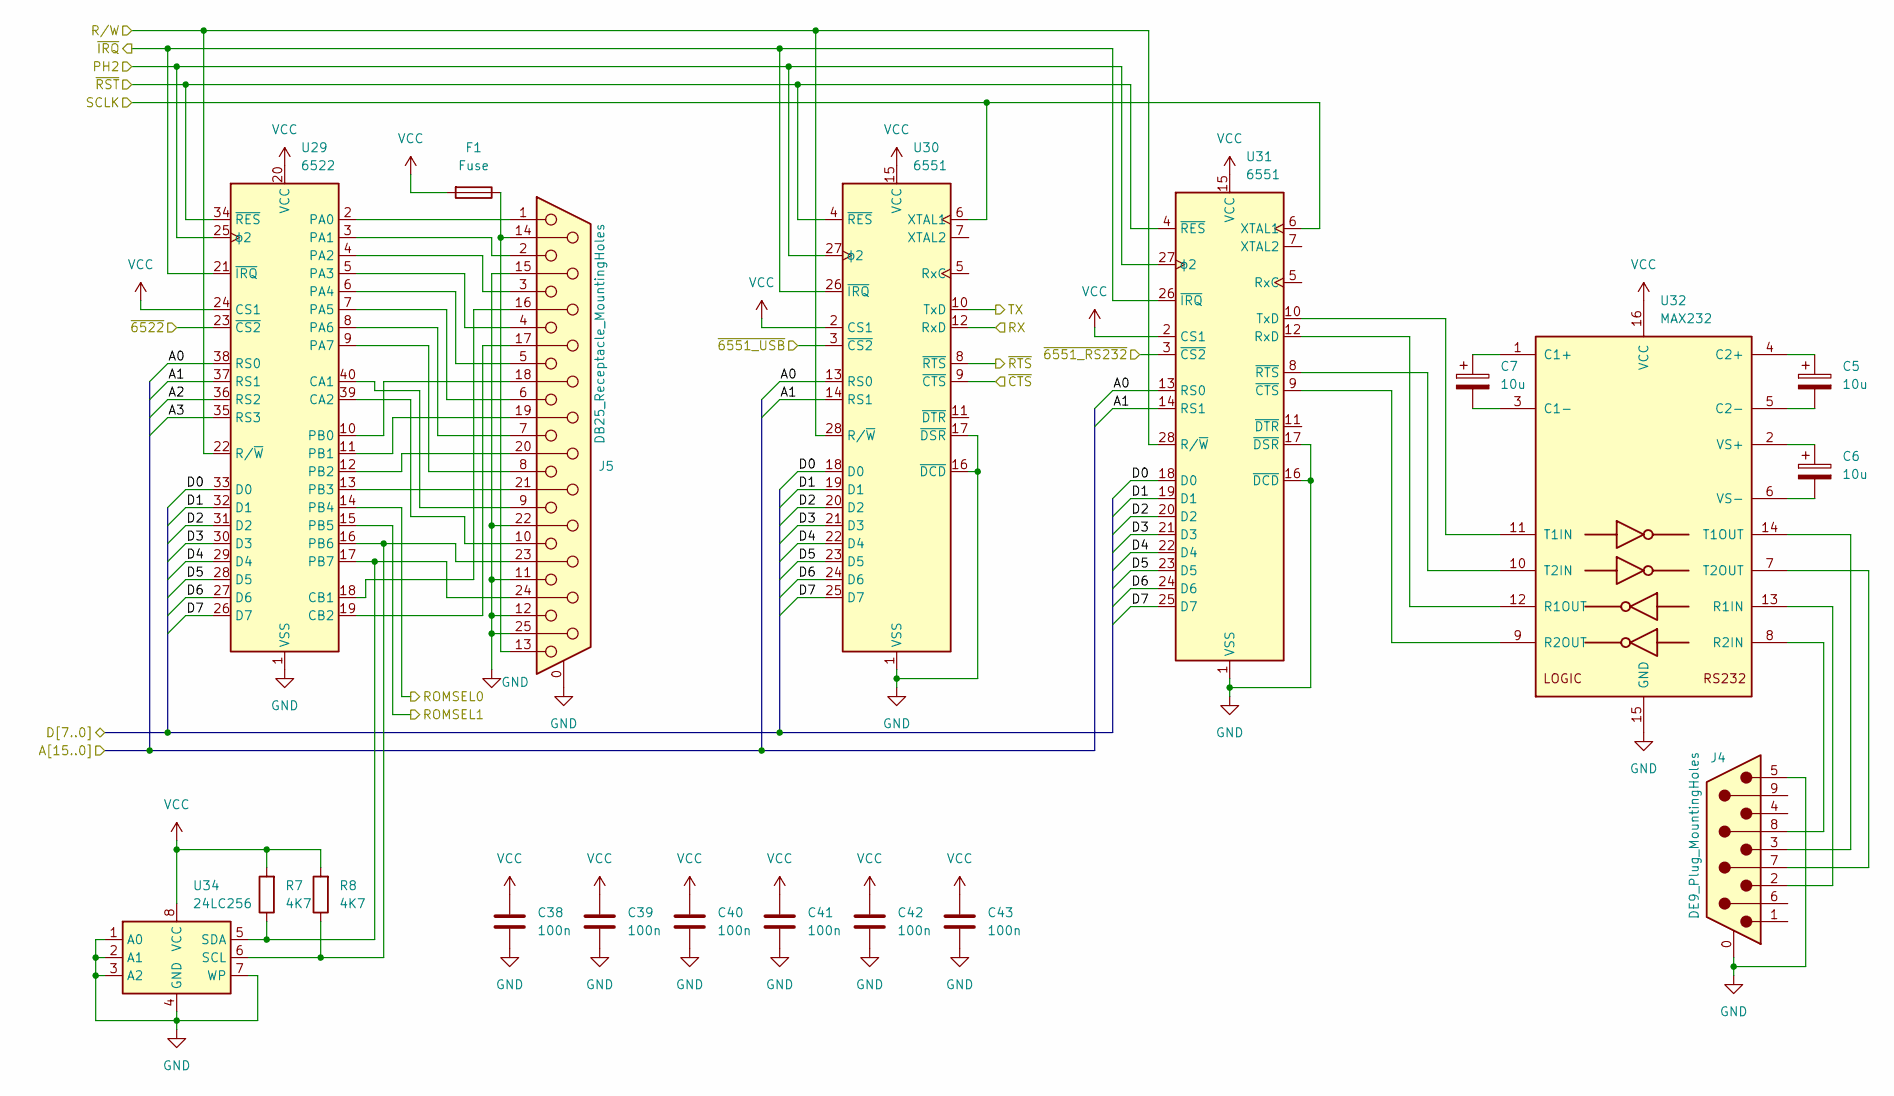
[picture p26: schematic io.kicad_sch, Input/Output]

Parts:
C5, C6, C7: 10u; CP_Radial_D6.3mm_P2.50mm
C38, C39, C40, C41, C42, C43: 100n; C_Disc_D5.0mm_W2.5mm_P2.50mm
F1: Fuse; Fuse_Littelfuse_395Series
J4: DE9_Plug_MountingHoles; DSUB-9_Male_Horizontal_P2.77x2.84mm_EdgePinOffset7.70mm_Hou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
J5: DB25_Receptacle_MountingHoles; DSUB-25_Socket_Horizontal_P2.77x2.84mm_EdgePinOffset7.70mm_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
R7, R8: 4K7; R_Axial_DIN0207_L6.3mm_D2.5mm_P7.62mm_Horizontal
U29: 6522; DIP-40_W15.24mm
U30, U31: 6551; DIP-28_W15.24mm
U32: MAX232; DIP-16_W7.62mm
U34: 24LC256; DIP-8_W7.62mm

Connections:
/clock/SCLK: U29.25 (ϕ2), U30.6 (XTAL1), U30.27 (ϕ2), U31.6 (XTAL1), U31.27 (ϕ2); also elsewhere on the board
/clock/~RST: U29.34 (~RES), U30.4 (~RES), U31.4 (~RES); also elsewhere on the board
/cpu/A0: U29.38 (RS0), U30.13 (RS0), U31.13 (RS0); also elsewhere on the board
/cpu/A1: U29.37 (RS1), U30.14 (RS1), U31.14 (RS1); also elsewhere on the board
/cpu/A2: U29.36 (RS2); also elsewhere on the board
/cpu/A3: U29.35 (RS3); also elsewhere on the board
/cpu/D0: U29.33 (D0), U30.18 (D0), U31.18 (D0); also elsewhere on the board
/cpu/D1: U29.32 (D1), U30.19 (D1), U31.19 (D1); also elsewhere on the board
/cpu/D2: U29.31 (D2), U30.20 (D2), U31.20 (D2); also elsewhere on the board
/cpu/D3: U29.30 (D3), U30.21 (D3), U31.21 (D3); also elsewhere on the board
/cpu/D4: U29.29 (D4), U30.22 (D4), U31.22 (D4); also elsewhere on the board
/cpu/D5: U29.28 (D5), U30.23 (D5), U31.23 (D5); also elsewhere on the board
/cpu/D6: U29.27 (D6), U30.24 (D6), U31.24 (D6); also elsewhere on the board
/cpu/D7: U29.26 (D7), U30.25 (D7), U31.25 (D7); also elsewhere on the board
/cpu/R/W: U29.22 (R/~W), U30.28 (R/~W), U31.28 (R/~W); also elsewhere on the board
/cpu/~IO4: U29.23 (~CS2); also elsewhere on the board
/cpu/~IO5: U30.3 (~CS2); also elsewhere on the board
/cpu/~IO6: U31.3 (~CS2); also elsewhere on the board
/cpu/~IRQ: U29.21 (~IRQ), U30.26 (~IRQ), U31.26 (~IRQ); also elsewhere on the board
/io/ROMSEL0: U29.14 (PB4); also elsewhere on the board
/io/ROMSEL1: U29.15 (PB5); also elsewhere on the board
/io/RX: U30.12 (RxD); also elsewhere on the board
/io/TX: U30.10 (TxD); also elsewhere on the board
/io/~CTS: U30.9 (~CTS)
/io/~RTS: U30.8 (~RTS)
GND: C38.2, C39.2, C40.2, C41.2, C42.2, C43.2, J4.0 (PAD), J4.5, J5.0 (PAD), J5.11, J5.12, J5.15, J5.22, J5.25, U29.1 (VSS), U30.1 (VSS), U30.16 (~DCD), U30.17 (~DSR), U31.1 (VSS), U31.16 (~DCD), U31.17 (~DSR), U32.15 (GND), U34.1 (A0), U34.2 (A1), U34.3 (A2), U34.4 (GND), U34.7 (WP); also elsewhere on the board
unnamed: F1.1, J5.13, J5.14
unnamed: J5.16, U29.18 (CB1)
unnamed: J5.17, U29.19 (CB2)
unnamed: J5.18, U29.10 (PB0)
unnamed: J5.19, U29.11 (PB1)
unnamed: J5.20, U29.12 (PB2)
unnamed: J5.21, U29.13 (PB3)
unnamed: J5.23, R8.1, U29.16 (PB6), U34.6 (SCL)
unnamed: J5.24, R7.1, U29.17 (PB7), U34.5 (SDA)
unnamed: J5.9, U29.40 (CA1)
unnamed: J5.10, U29.39 (CA2)
unnamed: J5.1, U29.2 (PA0)
unnamed: J5.2, U29.3 (PA1)
unnamed: J5.3, U29.4 (PA2)
unnamed: J5.4, U29.5 (PA3)
unnamed: J5.5, U29.6 (PA4)
unnamed: J5.6, U29.7 (PA5)
unnamed: J5.7, U29.8 (PA6)
unnamed: J5.8, U29.9 (PA7)
unnamed: U31.12 (RxD), U32.12 (R1OUT)
unnamed: U31.10 (TxD), U32.11 (T1IN)
unnamed: U31.9 (~CTS), U32.9 (R2OUT)
unnamed: U31.8 (~RTS), U32.10 (T2IN)
unnamed: C7.1, U32.1 (C1+)
unnamed: C7.2, U32.3 (C1-)
unnamed: C5.1, U32.4 (C2+)
unnamed: C5.2, U32.5 (C2-)
unnamed: J4.2, U32.13 (R1IN)
unnamed: J4.8, U32.8 (R2IN)
unnamed: J4.3, U32.14 (T1OUT)
unnamed: J4.7, U32.7 (T2OUT)
unnamed: C6.1, U32.2 (VS+)
unnamed: C6.2, U32.6 (VS-)
VCC: C38.1, C39.1, C40.1, C41.1, C42.1, C43.1, F1.2, R7.2, R8.2, U29.20 (VCC), U29.24 (CS1), U30.2 (CS1), U30.15 (VCC), U31.2 (CS1), U31.15 (VCC), U32.16 (VCC), U34.8 (VCC); also elsewhere on the board

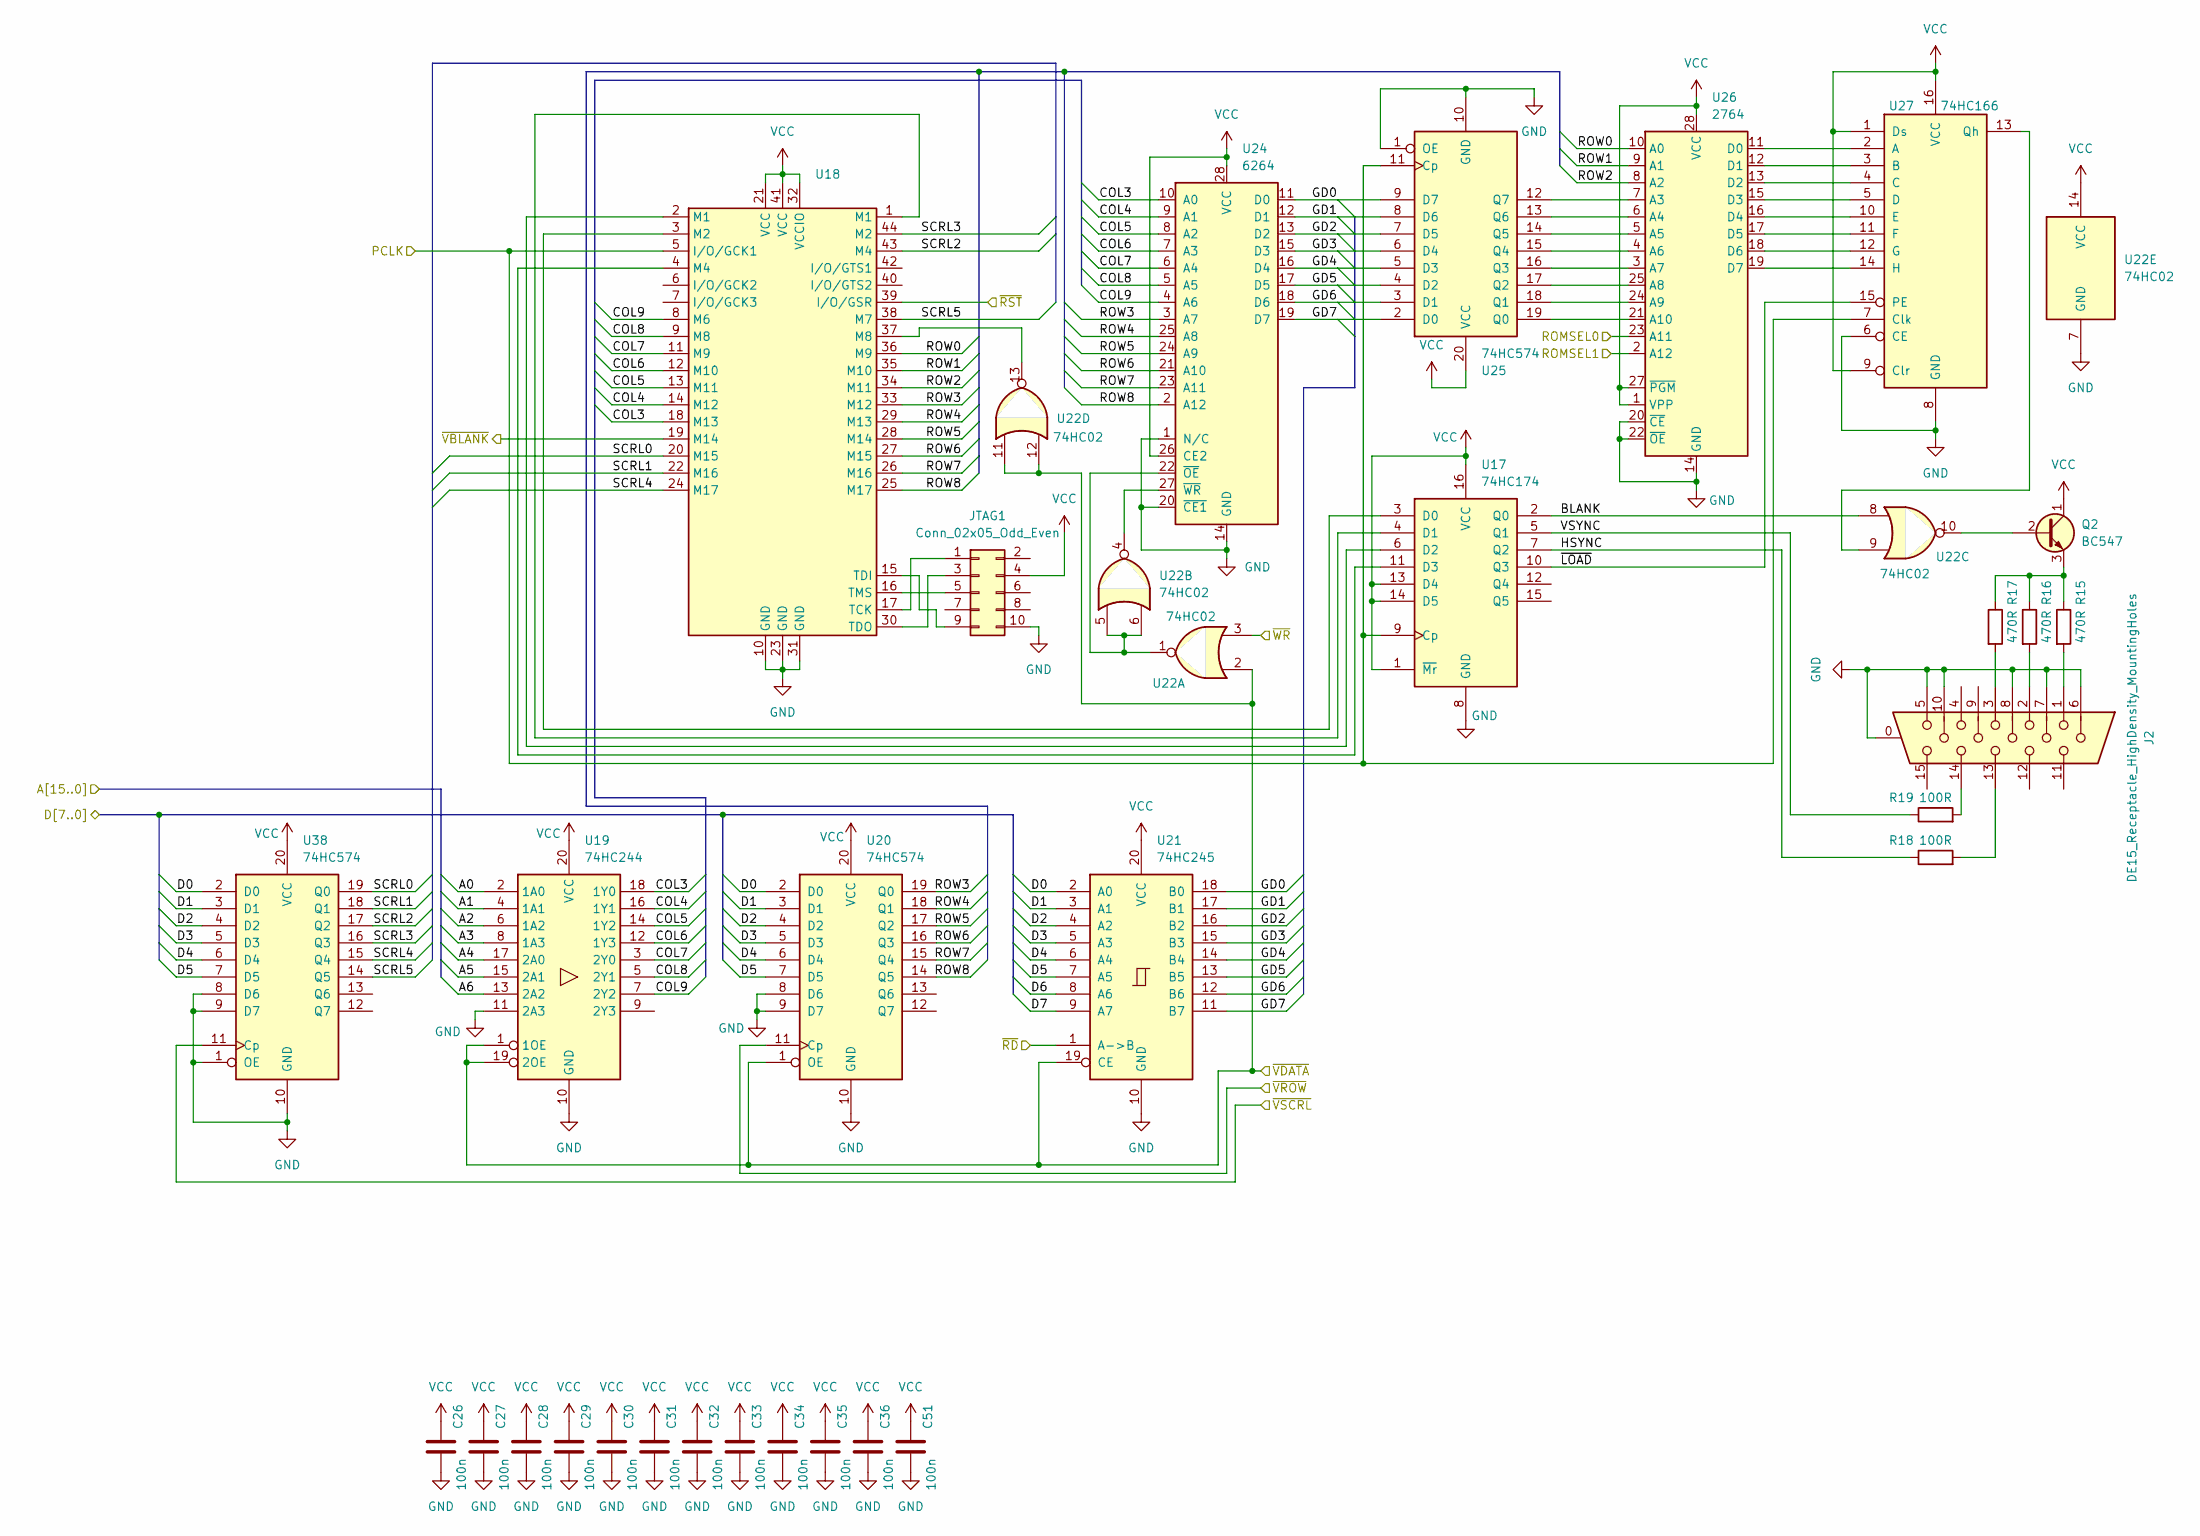
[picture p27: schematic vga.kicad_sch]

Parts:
C26, C27, C28, C29, C30, C31, C32, C33, C34, C35, C36, C51: 100n; C_Disc_D5.0mm_W2.5mm_P2.50mm
J2: DE15_Receptacle_HighDensity_MountingHoles; DSUB-15-HD_Female_Horizontal_P2.29x1.98mm_EdgePinOffset3.03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
JTAG1: Conn_02x05_Odd_Even; IDC-Header_2x05_P2.54mm_Vertical
Q2: BC547; TO-92
R15, R16, R17: 470R; R_Axial_DIN0207_L6.3mm_D2.5mm_P7.62mm_Horizontal
R18, R19: 100R; R_Axial_DIN0207_L6.3mm_D2.5mm_P7.62mm_Horizontal
U17: 74HC174; DIP-16_W7.62mm
U18: XC9536PC44; PLCC-44_THT-Socket
U19: 74HC244; DIP-20_W7.62mm
U20, U25, U38: 74HC574; DIP-20_W7.62mm
U21: 74HC245; DIP-20_W7.62mm
U22: 74HC02; DIP-14_W7.62mm
U24: 6264; DIP-28_W15.24mm
U26: 2764; DIP-28_W15.24mm
U27: 74HC166; DIP-16_W7.62mm

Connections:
/clock/PCLK: U17.9 (Cp), U18.5 (I/O/GCK1), U25.11 (Cp), U27.7 (Clk); also elsewhere on the board
/clock/~RST: U18.39 (I/O/GSR); also elsewhere on the board
/cpu/A0: U19.2 (1A0); also elsewhere on the board
/cpu/A1: U19.4 (1A1); also elsewhere on the board
/cpu/A2: U19.6 (1A2); also elsewhere on the board
/cpu/A3: U19.8 (1A3); also elsewhere on the board
/cpu/A4: U19.17 (2A0); also elsewhere on the board
/cpu/A5: U19.15 (2A1); also elsewhere on the board
/cpu/A6: U19.13 (2A2); also elsewhere on the board
/cpu/D0: U20.2 (D0), U21.2 (A0), U38.2 (D0); also elsewhere on the board
/cpu/D1: U20.3 (D1), U21.3 (A1), U38.3 (D1); also elsewhere on the board
/cpu/D2: U20.4 (D2), U21.4 (A2), U38.4 (D2); also elsewhere on the board
/cpu/D3: U20.5 (D3), U21.5 (A3), U38.5 (D3); also elsewhere on the board
/cpu/D4: U20.6 (D4), U21.6 (A4), U38.6 (D4); also elsewhere on the board
/cpu/D5: U20.7 (D5), U21.7 (A5), U38.7 (D5); also elsewhere on the board
/cpu/D6: U21.8 (A6); also elsewhere on the board
/cpu/D7: U21.9 (A7); also elsewhere on the board
/cpu/~IO0: U19.1 (1OE), U19.19 (2OE), U20.1 (OE), U21.19 (CE), U22.2, U22.11, U22.12; also elsewhere on the board
/cpu/~IO1: U20.11 (Cp); also elsewhere on the board
/cpu/~IO2: U38.11 (Cp); also elsewhere on the board
/cpu/~NMI: U18.19 (M14); also elsewhere on the board
/cpu/~RD: U21.1 (A->B); also elsewhere on the board
/cpu/~WR: U22.3; also elsewhere on the board
/io/ROMSEL0: U26.23 (A11); also elsewhere on the board
/io/ROMSEL1: U26.2 (A12); also elsewhere on the board
/vga/BLANK: U17.2 (Q0), U22.8
/vga/COL3: U18.18 (M13), U19.18 (1Y0), U24.10 (A0)
/vga/COL4: U18.14 (M12), U19.16 (1Y1), U24.9 (A1)
/vga/COL5: U18.13 (M11), U19.14 (1Y2), U24.8 (A2)
/vga/COL6: U18.12 (M10), U19.12 (1Y3), U24.7 (A3)
/vga/COL7: U18.11 (M9), U19.3 (2Y0), U24.6 (A4)
/vga/COL8: U18.9 (M8), U19.5 (2Y1), U24.5 (A5)
/vga/COL9: U18.8 (M6), U19.7 (2Y2), U24.4 (A6)
/vga/GD0: U21.18 (B0), U24.11 (D0), U25.9 (D7)
/vga/GD1: U21.17 (B1), U24.12 (D1), U25.8 (D6)
/vga/GD2: U21.16 (B2), U24.13 (D2), U25.7 (D5)
/vga/GD3: U21.15 (B3), U24.15 (D3), U25.6 (D4)
/vga/GD4: U21.14 (B4), U24.16 (D4), U25.5 (D3)
/vga/GD5: U21.13 (B5), U24.17 (D5), U25.4 (D2)
/vga/GD6: U21.12 (B6), U24.18 (D6), U25.3 (D1)
/vga/GD7: U21.11 (B7), U24.19 (D7), U25.2 (D0)
/vga/HSYNC: R18.1, U17.7 (Q2)
/vga/ROW0: U18.36 (M9), U26.10 (A0)
/vga/ROW1: U18.35 (M10), U26.9 (A1)
/vga/ROW2: U18.34 (M11), U26.8 (A2)
/vga/ROW3: U18.33 (M12), U20.19 (Q0), U24.3 (A7)
/vga/ROW4: U18.29 (M13), U20.18 (Q1), U24.25 (A8)
/vga/ROW5: U18.28 (M14), U20.17 (Q2), U24.24 (A9)
/vga/ROW6: U18.27 (M15), U20.16 (Q3), U24.21 (A10)
/vga/ROW7: U18.26 (M16), U20.15 (Q4), U24.23 (A11)
/vga/ROW8: U18.25 (M17), U20.14 (Q5), U24.2 (A12)
/vga/SCRL0: U18.20 (M15), U38.19 (Q0)
/vga/SCRL1: U18.22 (M16), U38.18 (Q1)
/vga/SCRL2: U18.43 (M4), U38.17 (Q2)
/vga/SCRL3: U18.44 (M2), U38.16 (Q3)
/vga/SCRL4: U18.24 (M17), U38.15 (Q4)
/vga/SCRL5: U18.38 (M7), U38.14 (Q5)
/vga/VSYNC: R19.1, U17.5 (Q1)
/vga/~LOAD: U17.10 (Q3), U27.15 (PE)
GND: C26.2, C27.2, C28.2, C29.2, C30.2, C31.2, C32.2, C33.2, C34.2, C35.2, C36.2, C51.2, J2.0, J2.5, J2.6, J2.7, J2.8, J2.10, JTAG1.10, U17.8 (GND), U18.10 (GND), U18.23 (GND), U18.31 (GND), U19.10 (GND), U19.11 (2A3), U20.8 (D6), U20.9 (D7), U20.10 (GND), U21.10 (GND), U22.7 (GND), U24.1 (N/C), U24.14 (GND), U24.20 (~CE1), U25.1 (OE), U25.10 (GND), U26.14 (GND), U26.20 (~CE), U26.22 (~OE), U27.6 (CE), U27.8 (GND), U38.1 (OE), U38.8 (D6), U38.9 (D7), U38.10 (GND); also elsewhere on the board
unnamed: J2.1, R15.2
unnamed: J2.2, R16.2
unnamed: J2.3, R17.2
unnamed: J2.13, R18.2
unnamed: J2.14, R19.2
unnamed: JTAG1.1, U18.17 (TCK)
unnamed: JTAG1.3, U18.30 (TDO)
unnamed: JTAG1.5, U18.16 (TMS)
unnamed: JTAG1.9, U18.15 (TDI)
unnamed: Q2.2 (B), U22.10
unnamed: Q2.3 (E), R15.1, R16.1, R17.1
unnamed: U17.3 (D0), U18.3 (M2)
unnamed: U17.4 (D1), U18.1 (M1)
unnamed: U17.6 (D2), U18.2 (M1)
unnamed: U17.11 (D3), U18.4 (M4)
unnamed: U18.37 (M8), U22.13
unnamed: U22.1, U22.5, U22.6, U24.22 (~OE)
unnamed: U22.4, U24.27 (~WR)
unnamed: U25.19 (Q0), U26.21 (A10)
unnamed: U25.18 (Q1), U26.24 (A9)
unnamed: U25.17 (Q2), U26.25 (A8)
unnamed: U25.16 (Q3), U26.3 (A7)
unnamed: U25.15 (Q4), U26.4 (A6)
unnamed: U25.14 (Q5), U26.5 (A5)
unnamed: U25.13 (Q6), U26.6 (A4)
unnamed: U25.12 (Q7), U26.7 (A3)
unnamed: U26.11 (D0), U27.2 (A)
unnamed: U26.12 (D1), U27.3 (B)
unnamed: U26.13 (D2), U27.4 (C)
unnamed: U26.15 (D3), U27.5 (D)
unnamed: U26.16 (D4), U27.10 (E)
unnamed: U26.17 (D5), U27.11 (F)
unnamed: U26.18 (D6), U27.12 (G)
unnamed: U26.19 (D7), U27.14 (H)
unnamed: U22.9, U27.13 (Qh)
VCC: C26.1, C27.1, C28.1, C29.1, C30.1, C31.1, C32.1, C33.1, C34.1, C35.1, C36.1, C51.1, JTAG1.4, Q2.1 (C), U17.1 (~Mr), U17.13 (D4), U17.14 (D5), U17.16 (VCC), U18.21 (VCC), U18.32 (VCCIO), U18.41 (VCC), U19.20 (VCC), U20.20 (VCC), U21.20 (VCC), U22.14 (VCC), U24.26 (CE2), U24.28 (VCC), U25.20 (VCC), U26.1 (VPP), U26.27 (~PGM), U26.28 (VCC), U27.1 (Ds), U27.9 (Clr), U27.16 (VCC), U38.20 (VCC); also elsewhere on the board

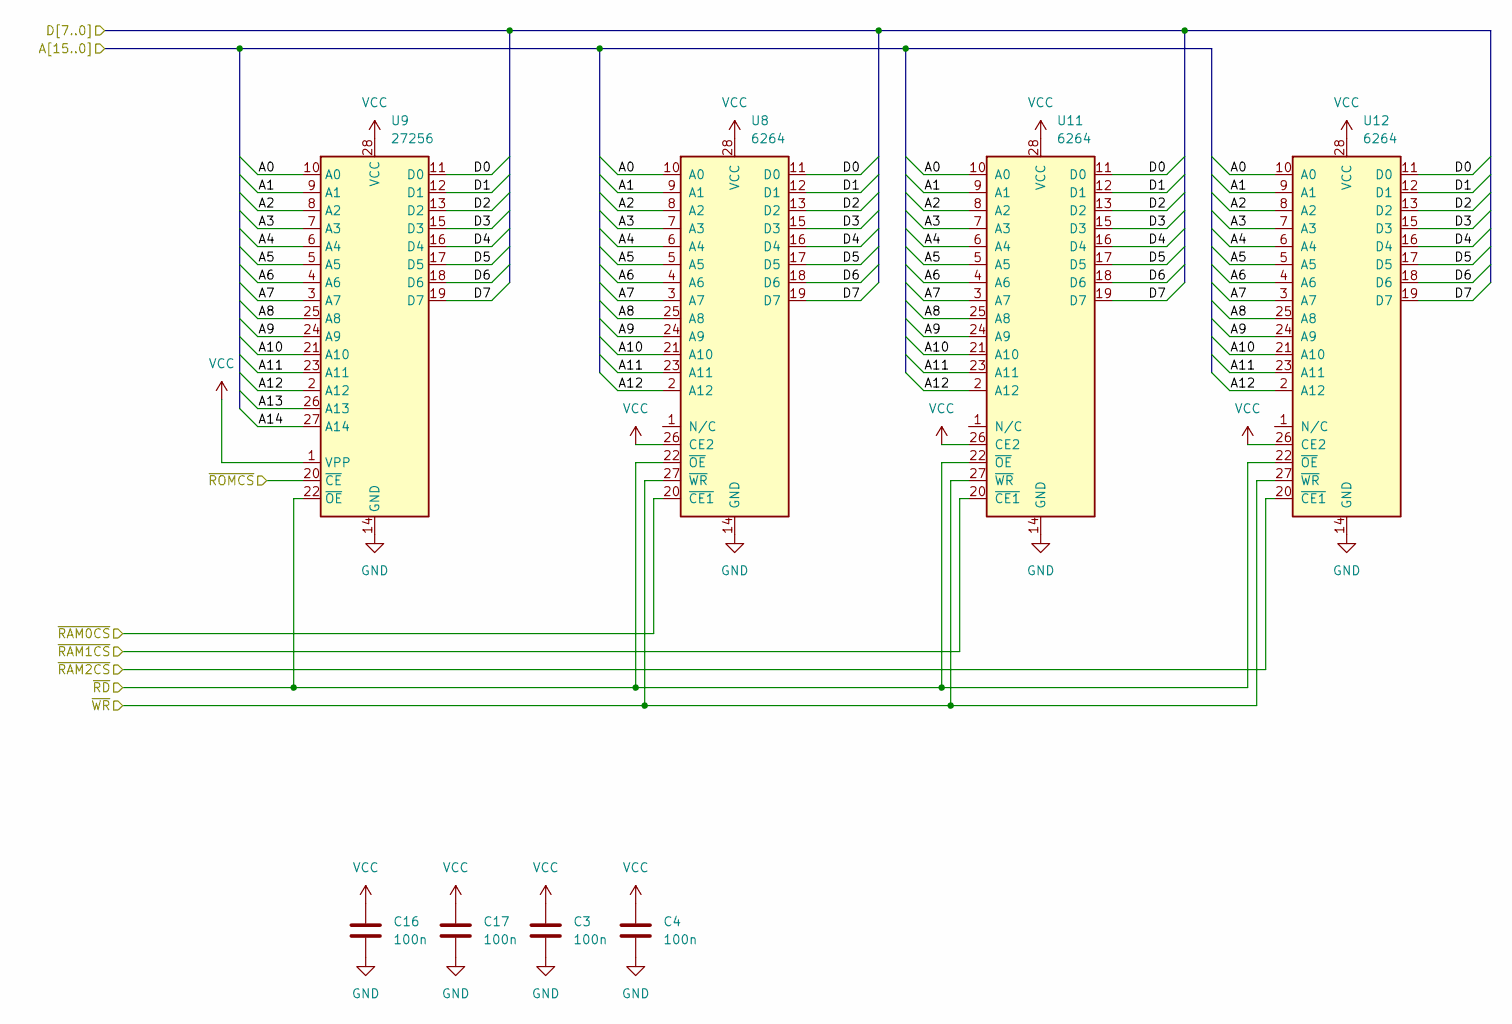
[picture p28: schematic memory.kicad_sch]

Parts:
C3, C4, C16, C17: 100n; C_Disc_D5.0mm_W2.5mm_P2.50mm
U8, U11, U12: 6264; DIP-28_W15.24mm
U9: 27256; DIP-28_W15.24mm

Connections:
/cpu/A0: U8.10 (A0), U9.10 (A0), U11.10 (A0), U12.10 (A0); also elsewhere on the board
/cpu/A1: U8.9 (A1), U9.9 (A1), U11.9 (A1), U12.9 (A1); also elsewhere on the board
/cpu/A2: U8.8 (A2), U9.8 (A2), U11.8 (A2), U12.8 (A2); also elsewhere on the board
/cpu/A3: U8.7 (A3), U9.7 (A3), U11.7 (A3), U12.7 (A3); also elsewhere on the board
/cpu/A4: U8.6 (A4), U9.6 (A4), U11.6 (A4), U12.6 (A4); also elsewhere on the board
/cpu/A5: U8.5 (A5), U9.5 (A5), U11.5 (A5), U12.5 (A5); also elsewhere on the board
/cpu/A6: U8.4 (A6), U9.4 (A6), U11.4 (A6), U12.4 (A6); also elsewhere on the board
/cpu/A7: U8.3 (A7), U9.3 (A7), U11.3 (A7), U12.3 (A7); also elsewhere on the board
/cpu/A8: U8.25 (A8), U9.25 (A8), U11.25 (A8), U12.25 (A8); also elsewhere on the board
/cpu/A9: U8.24 (A9), U9.24 (A9), U11.24 (A9), U12.24 (A9); also elsewhere on the board
/cpu/A10: U8.21 (A10), U9.21 (A10), U11.21 (A10), U12.21 (A10); also elsewhere on the board
/cpu/A11: U8.23 (A11), U9.23 (A11), U11.23 (A11), U12.23 (A11); also elsewhere on the board
/cpu/A12: U8.2 (A12), U9.2 (A12), U11.2 (A12), U12.2 (A12); also elsewhere on the board
/cpu/A13: U9.26 (A13); also elsewhere on the board
/cpu/A14: U9.27 (A14); also elsewhere on the board
/cpu/D0: U8.11 (D0), U9.11 (D0), U11.11 (D0), U12.11 (D0); also elsewhere on the board
/cpu/D1: U8.12 (D1), U9.12 (D1), U11.12 (D1), U12.12 (D1); also elsewhere on the board
/cpu/D2: U8.13 (D2), U9.13 (D2), U11.13 (D2), U12.13 (D2); also elsewhere on the board
/cpu/D3: U8.15 (D3), U9.15 (D3), U11.15 (D3), U12.15 (D3); also elsewhere on the board
/cpu/D4: U8.16 (D4), U9.16 (D4), U11.16 (D4), U12.16 (D4); also elsewhere on the board
/cpu/D5: U8.17 (D5), U9.17 (D5), U11.17 (D5), U12.17 (D5); also elsewhere on the board
/cpu/D6: U8.18 (D6), U9.18 (D6), U11.18 (D6), U12.18 (D6); also elsewhere on the board
/cpu/D7: U8.19 (D7), U9.19 (D7), U11.19 (D7), U12.19 (D7); also elsewhere on the board
/cpu/~RAM0CS: U8.20 (~CE1); also elsewhere on the board
/cpu/~RAM1CS: U11.20 (~CE1); also elsewhere on the board
/cpu/~RAM2CS: U12.20 (~CE1); also elsewhere on the board
/cpu/~RD: U8.22 (~OE), U9.22 (~OE), U11.22 (~OE), U12.22 (~OE); also elsewhere on the board
/cpu/~ROMCS: U9.20 (~CE); also elsewhere on the board
/cpu/~WR: U8.27 (~WR), U11.27 (~WR), U12.27 (~WR); also elsewhere on the board
GND: C3.2, C4.2, C16.2, C17.2, U8.14 (GND), U9.14 (GND), U11.14 (GND), U12.14 (GND); also elsewhere on the board
VCC: C3.1, C4.1, C16.1, C17.1, U8.26 (CE2), U8.28 (VCC), U9.1 (VPP), U9.28 (VCC), U11.26 (CE2), U11.28 (VCC), U12.26 (CE2), U12.28 (VCC); also elsewhere on the board

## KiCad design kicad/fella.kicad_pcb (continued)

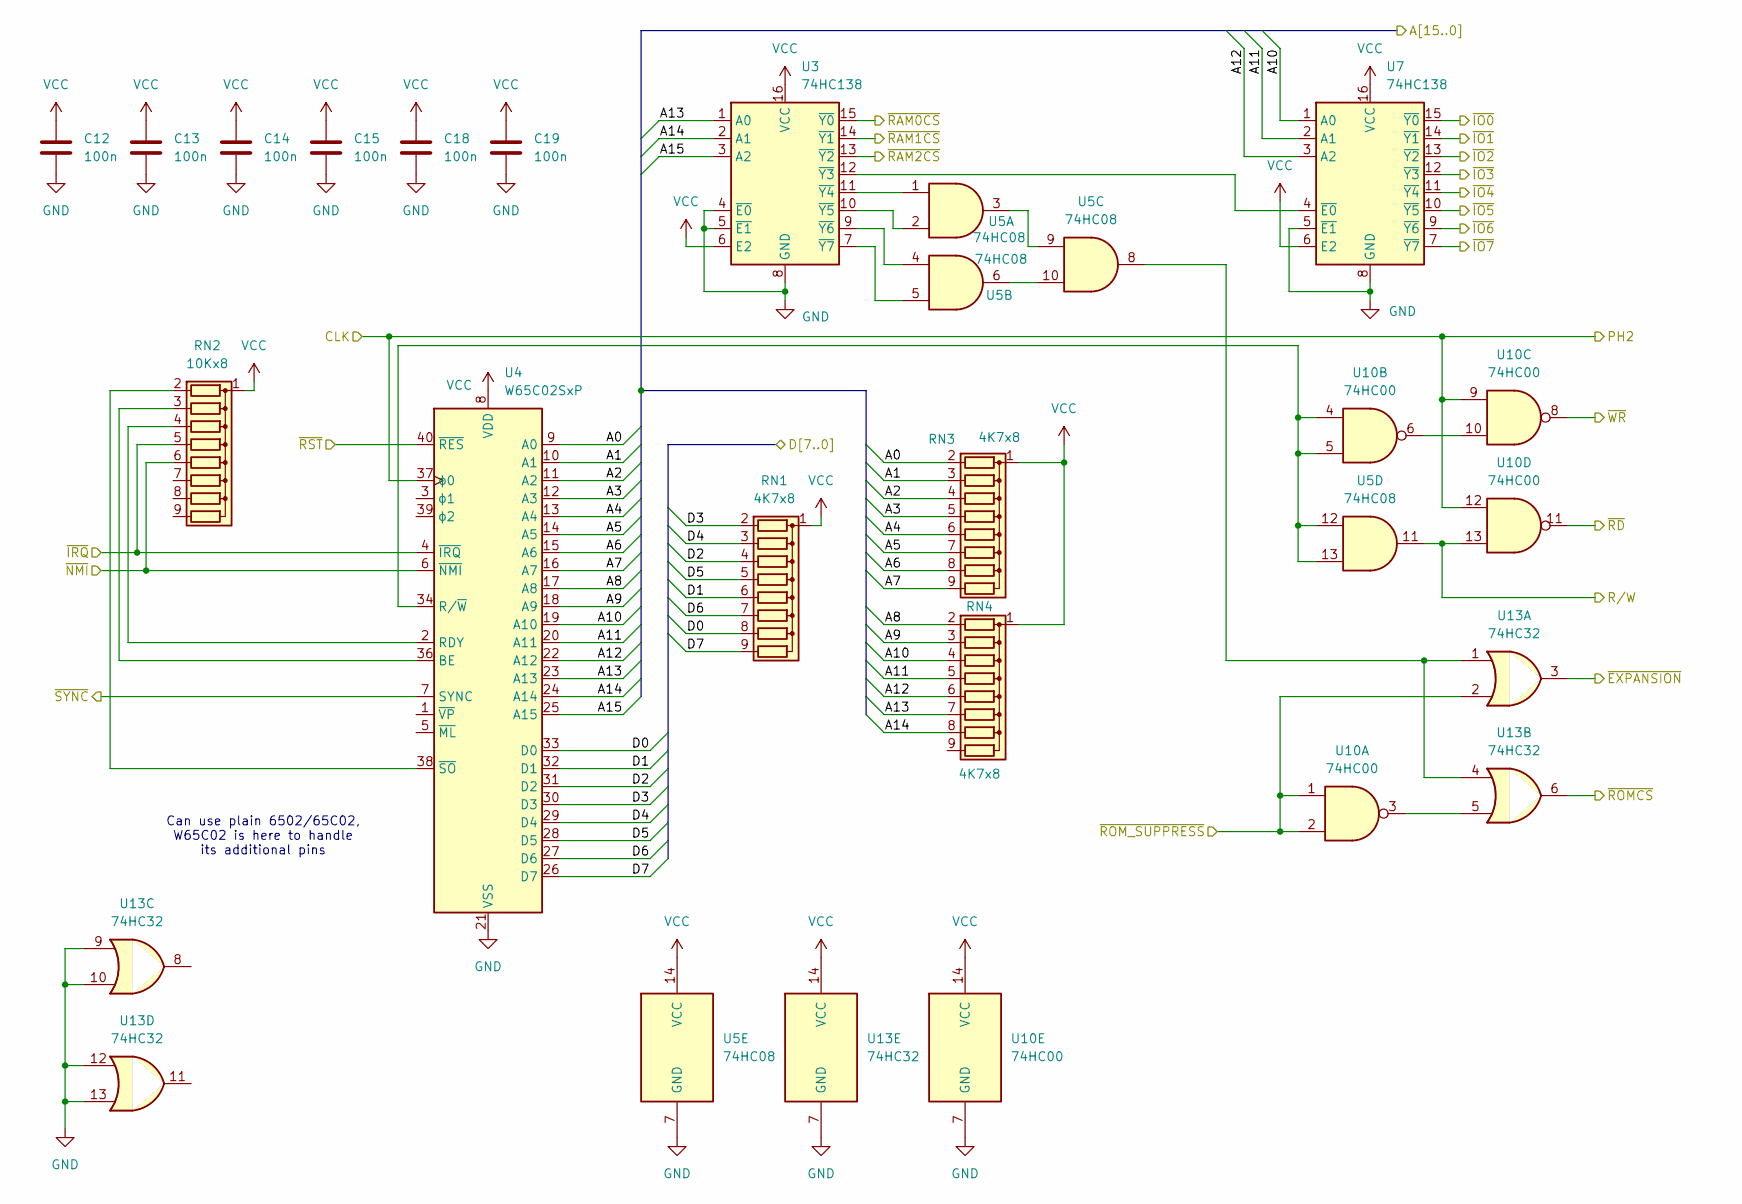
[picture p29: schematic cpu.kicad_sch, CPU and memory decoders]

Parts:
C12, C13, C14, C15, C18, C19: 100n; C_Disc_D5.0mm_W2.5mm_P2.50mm
RN1, RN3, RN4: 4K7x8; R_Array_SIP9
RN2: 10Kx8; R_Array_SIP9
U3, U7: 74HC138; DIP-16_W7.62mm
U4: W65C02SxP; DIP-40_W15.24mm
U5: 74HC08; DIP-14_W7.62mm
U10: 74HC00; DIP-14_W7.62mm
U13: 74HC32; DIP-14_W7.62mm

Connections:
/clock/SCLK: U4.37 (ϕ0), U10.9, U10.12; also elsewhere on the board
/clock/~RST: U4.40 (~RES); also elsewhere on the board
/cpu/A0: RN3.2 (R1), U4.9 (A0); also elsewhere on the board
/cpu/A1: RN3.3 (R2), U4.10 (A1); also elsewhere on the board
/cpu/A2: RN3.4 (R3), U4.11 (A2); also elsewhere on the board
/cpu/A3: RN3.5 (R4), U4.12 (A3); also elsewhere on the board
/cpu/A4: RN3.6 (R5), U4.13 (A4); also elsewhere on the board
/cpu/A5: RN3.7 (R6), U4.14 (A5); also elsewhere on the board
/cpu/A6: RN3.8 (R7), U4.15 (A6); also elsewhere on the board
/cpu/A7: RN3.9 (R8), U4.16 (A7); also elsewhere on the board
/cpu/A8: RN4.2 (R1), U4.17 (A8); also elsewhere on the board
/cpu/A9: RN4.3 (R2), U4.18 (A9); also elsewhere on the board
/cpu/A10: RN4.4 (R3), U4.19 (A10), U7.1 (A0); also elsewhere on the board
/cpu/A11: RN4.5 (R4), U4.20 (A11), U7.2 (A1); also elsewhere on the board
/cpu/A12: RN4.6 (R5), U4.22 (A12), U7.3 (A2); also elsewhere on the board
/cpu/A13: RN4.7 (R6), U3.1 (A0), U4.23 (A13); also elsewhere on the board
/cpu/A14: RN4.8 (R7), U3.2 (A1), U4.24 (A14); also elsewhere on the board
/cpu/A15: U3.3 (A2), U4.25 (A15)
/cpu/D0: RN1.8 (R7), U4.33 (D0); also elsewhere on the board
/cpu/D1: RN1.6 (R5), U4.32 (D1); also elsewhere on the board
/cpu/D2: RN1.4 (R3), U4.31 (D2); also elsewhere on the board
/cpu/D3: RN1.2 (R1), U4.30 (D3); also elsewhere on the board
/cpu/D4: RN1.3 (R2), U4.29 (D4); also elsewhere on the board
/cpu/D5: RN1.5 (R4), U4.28 (D5); also elsewhere on the board
/cpu/D6: RN1.7 (R6), U4.27 (D6); also elsewhere on the board
/cpu/D7: RN1.9 (R8), U4.26 (D7); also elsewhere on the board
/cpu/R/W: U5.11, U10.13; also elsewhere on the board
/cpu/~EXPANSION: U13.3; also elsewhere on the board
/cpu/~IO0: U7.15 (~Y0); also elsewhere on the board
/cpu/~IO1: U7.14 (~Y1); also elsewhere on the board
/cpu/~IO2: U7.13 (~Y2); also elsewhere on the board
/cpu/~IO3: U7.12 (~Y3); also elsewhere on the board
/cpu/~IO4: U7.11 (~Y4); also elsewhere on the board
/cpu/~IO5: U7.10 (~Y5); also elsewhere on the board
/cpu/~IO6: U7.9 (~Y6); also elsewhere on the board
/cpu/~IO7: U7.7 (~Y7)
/cpu/~IRQ: RN2.5 (R4), U4.4 (~IRQ); also elsewhere on the board
/cpu/~NMI: RN2.6 (R5), U4.6 (~NMI); also elsewhere on the board
/cpu/~RAM0CS: U3.15 (~Y0); also elsewhere on the board
/cpu/~RAM1CS: U3.14 (~Y1); also elsewhere on the board
/cpu/~RAM2CS: U3.13 (~Y2); also elsewhere on the board
/cpu/~RD: U10.11; also elsewhere on the board
/cpu/~ROMCS: U13.6; also elsewhere on the board
/cpu/~ROM_SUPPRESS: U10.1, U10.2, U13.2; also elsewhere on the board
/cpu/~SYNC: U4.7 (SYNC)
/cpu/~WR: U10.8; also elsewhere on the board
GND: C12.2, C13.2, C14.2, C15.2, C18.2, C19.2, U3.4 (~E0), U3.5 (~E1), U3.8 (GND), U4.21 (VSS), U5.7 (GND), U7.5 (~E1), U7.8 (GND), U10.7 (GND), U13.7 (GND), U13.9, U13.10, U13.12, U13.13; also elsewhere on the board
unnamed: RN2.2 (R1), U4.38 (~SO)
unnamed: RN2.3 (R2), U4.36 (BE)
unnamed: RN2.4 (R3), U4.2 (RDY)
unnamed: U3.12 (~Y3), U7.4 (~E0)
unnamed: U3.11 (~Y4), U5.1
unnamed: U3.10 (~Y5), U5.2
unnamed: U3.9 (~Y6), U5.4
unnamed: U3.7 (~Y7), U5.5
unnamed: U4.34 (R/~W), U5.12, U5.13, U10.4, U10.5
unnamed: U5.3, U5.9
unnamed: U5.6, U5.10
unnamed: U10.3, U13.5
unnamed: U10.6, U10.10
unnamed: U5.8, U13.1, U13.4
VCC: C12.1, C13.1, C14.1, C15.1, C18.1, C19.1, RN1.1 (common), RN2.1 (common), RN3.1 (common), RN4.1 (common), U3.6 (E2), U3.16 (VCC), U4.8 (VDD), U5.14 (VCC), U7.6 (E2), U7.16 (VCC), U10.14 (VCC), U13.14 (VCC); also elsewhere on the board

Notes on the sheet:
Can use plain 6502/65C02, W65C02 is here to handle its additional pins

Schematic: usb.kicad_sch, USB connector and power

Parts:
C8, C44: 100n; C_Disc_D5.0mm_W2.5mm_P2.50mm
C48, C49: 470u; CP_Radial_D10.0mm_P5.00mm
J3: USB_C_Receptacle_USB2.0_14P; USB_C_Receptacle_G-Switch_GT-USB-7010ASV
R5, R6: 1K5; R_Axial_DIN0207_L6.3mm_D2.5mm_P7.62mm_Horizontal
U33: CH340N; SOP-8_3.9x4.9mm_P1.27mm

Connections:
/io/RX: U33.6 (TXD); also elsewhere on the board
/io/TX: U33.7 (RXD); also elsewhere on the board
GND: C8.2, C44.2, C48.2, C49.2, J3.A1 (GND), J3.A12 (GND), J3.B1 (GND), J3.B12 (GND), J3.S1 (SHIELD), R5.2, R6.2, U33.3 (GND); also elsewhere on the board
unnamed: J3.A5 (CC1), R6.1
unnamed: J3.B5 (CC2), R5.1
unnamed: J3.A6 (D+), J3.B6 (D+), U33.1 (UD+)
unnamed: J3.A7 (D-), J3.B7 (D-), U33.2 (UD-)
unnamed: C8.1, U33.8 (V3)
VCC: C44.1, C48.1, C49.1, J3.A4 (VBUS), J3.A9 (VBUS), J3.B4 (VBUS), J3.B9 (VBUS), U33.5 (VCC); also elsewhere on the board

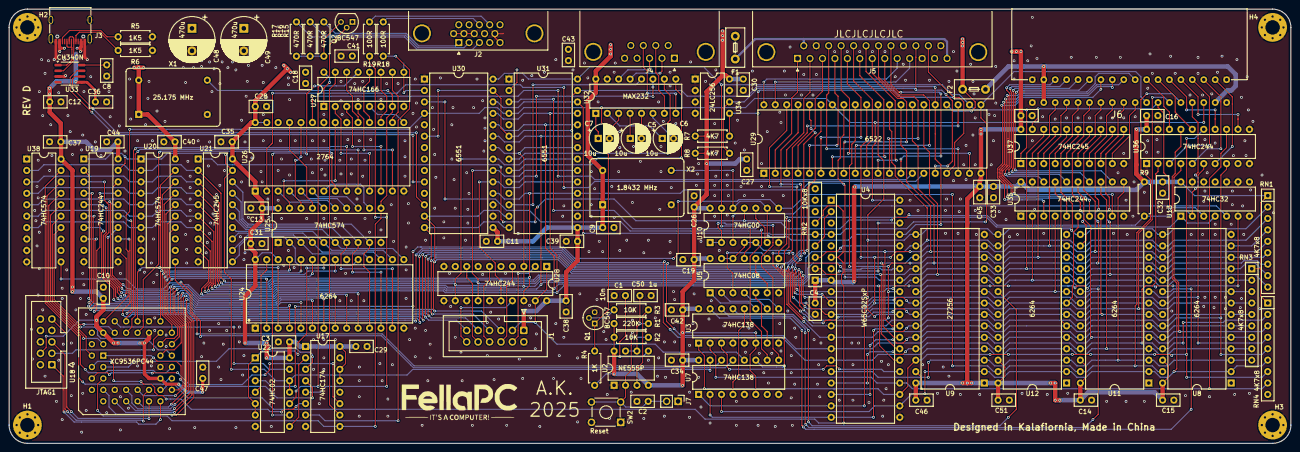
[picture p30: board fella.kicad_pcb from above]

Board: 2 copper layers, 284.9 x 96.5 mm, 114 parts (0 on the bottom side), 206 nets.

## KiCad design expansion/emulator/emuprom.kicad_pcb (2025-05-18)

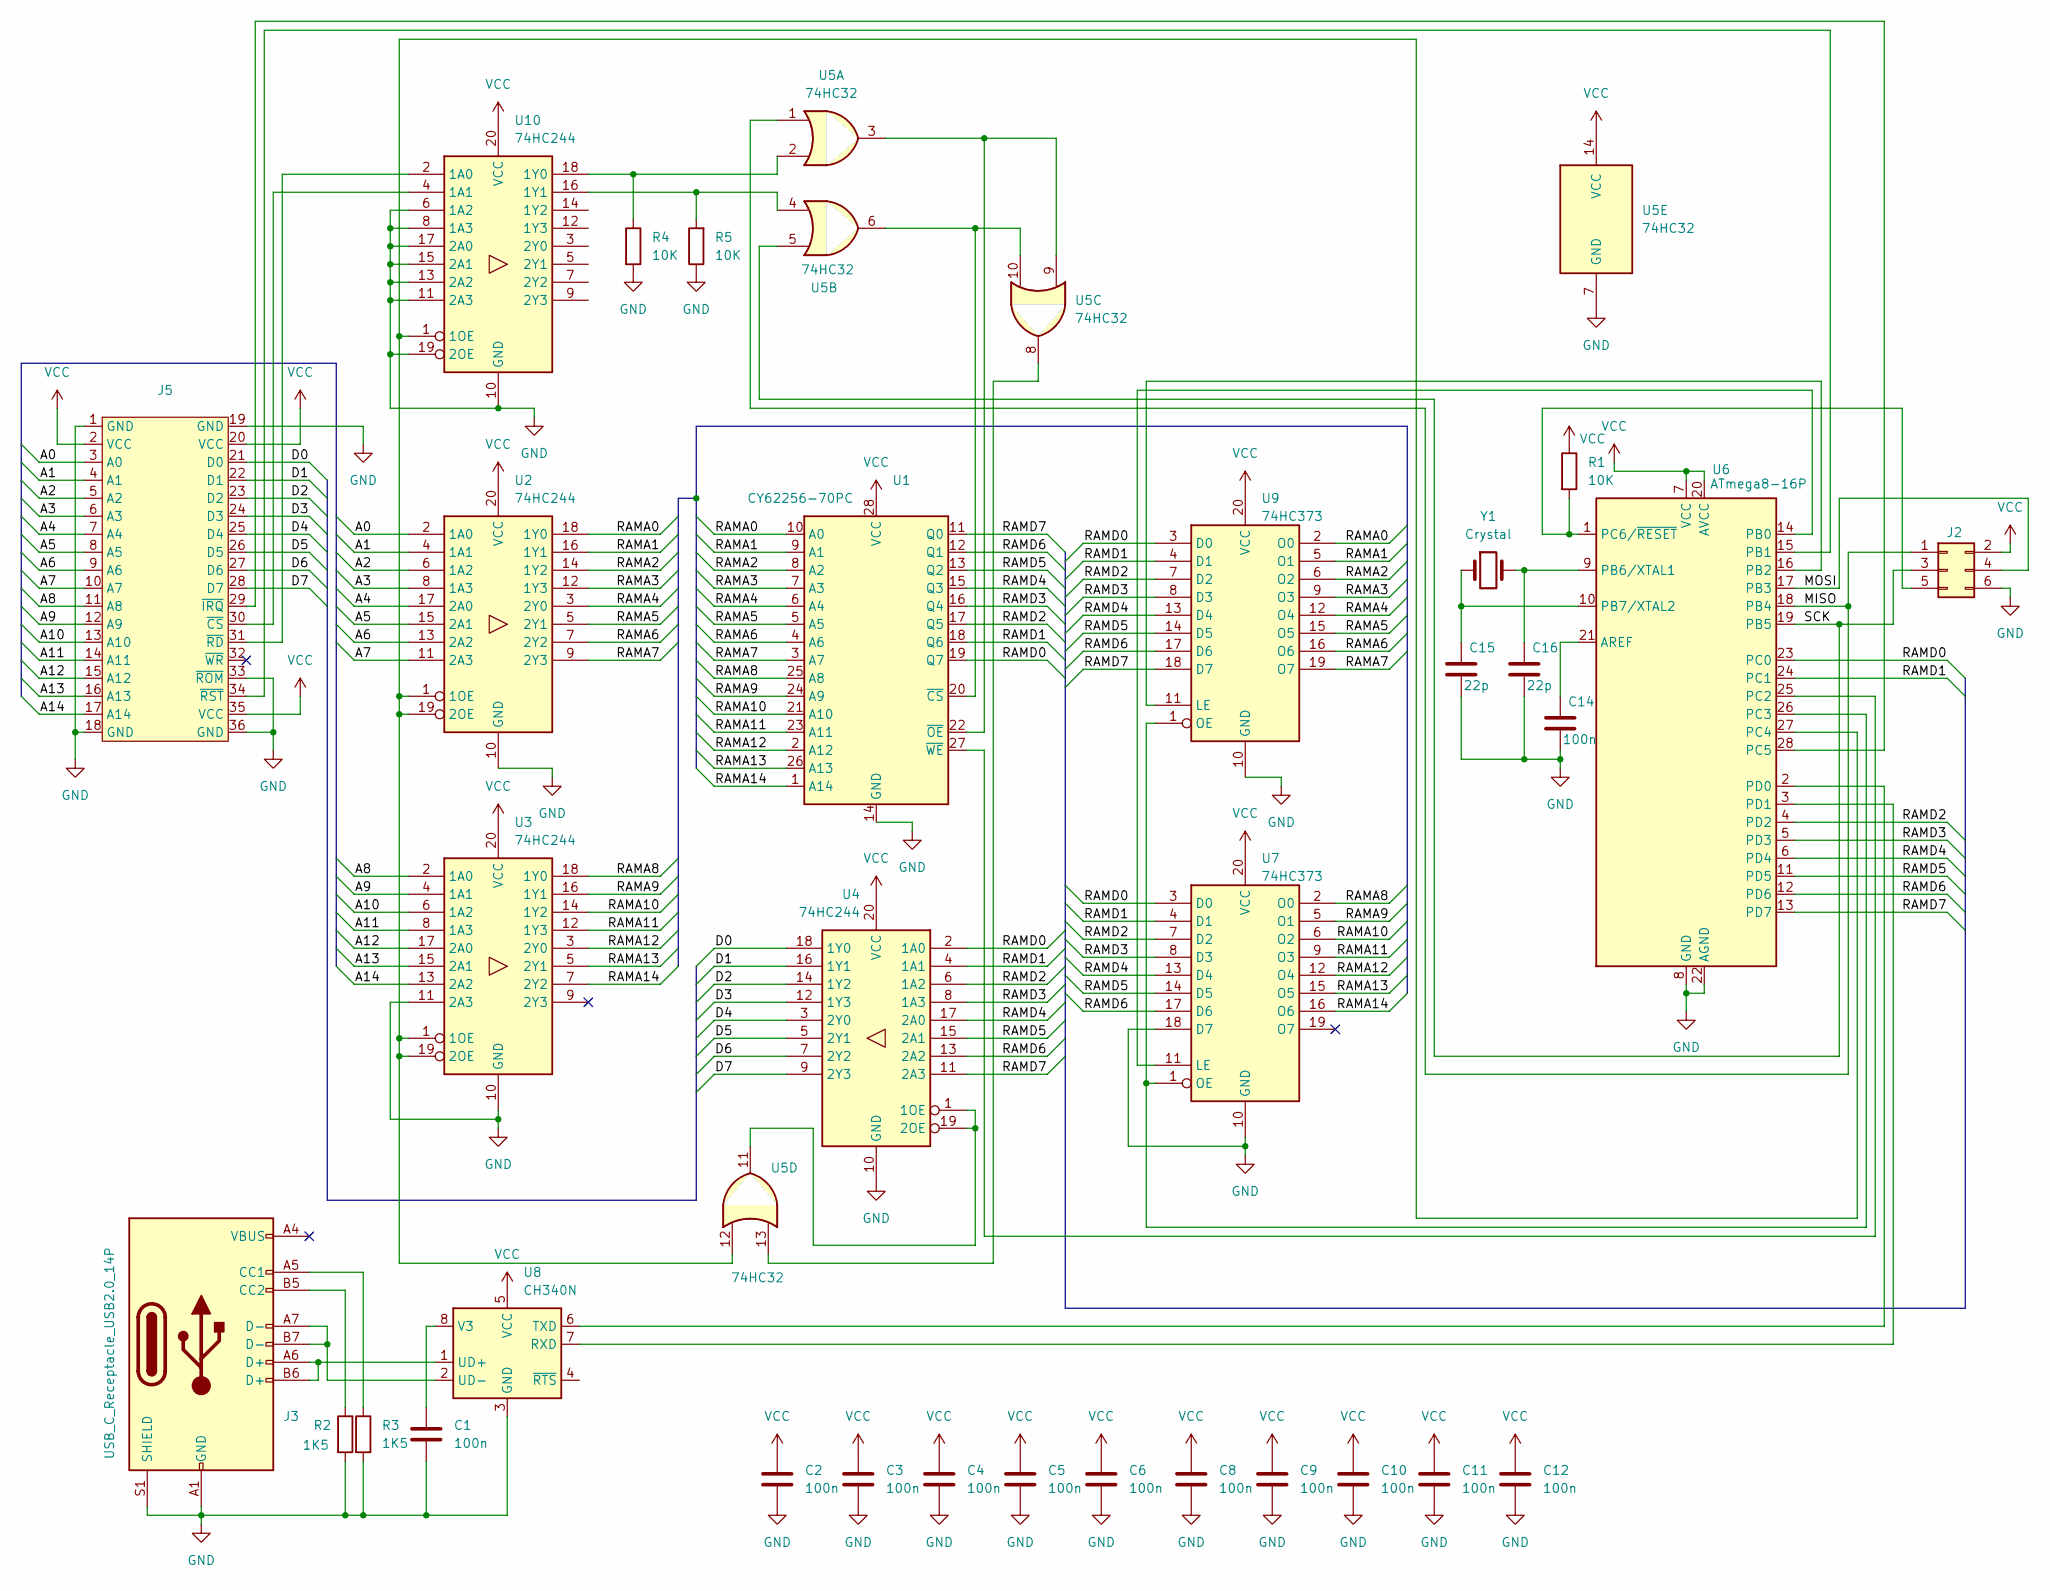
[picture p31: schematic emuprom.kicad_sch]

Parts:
C1, C2, C3, C4, C5, C6, C8, C9, C10, C11, C12, C14: 100n; C_Disc_D3.0mm_W1.6mm_P2.50mm
C15, C16: 22p; C_Disc_D3.0mm_W1.6mm_P2.50mm
J2: Conn_02x03_Odd_Even; IDC-Header_2x03_P2.54mm_Vertical
J3: USB_C_Receptacle_USB2.0_14P; USB_C_Receptacle_GCT_USB4105-xx-A_16P_TopMnt_Horizontal
J5: Expansion Connector
R1, R4, R5: 10K; R_Axial_DIN0207_L6.3mm_D2.5mm_P7.62mm_Horizontal
R2, R3: 1K5; R_Axial_DIN0207_L6.3mm_D2.5mm_P7.62mm_Horizontal
U1: CY62256-70PC; DIP-28_W15.24mm
U2, U3, U4, U10: 74HC244; DIP-20_W7.62mm
U5: 74HC32; DIP-14_W7.62mm
U6: ATmega8-16P; DIP-28_W7.62mm
U7, U9: 74HC373; DIP-20_W7.62mm
U8: CH340N; SOP-8_3.9x4.9mm_P1.27mm
Y1: Crystal; Crystal_HC49-4H_Vertical

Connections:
/A0: J5.3 (A0), U2.2 (1A0)
/A1: J5.4 (A1), U2.4 (1A1)
/A2: J5.5 (A2), U2.6 (1A2)
/A3: J5.6 (A3), U2.8 (1A3)
/A4: J5.7 (A4), U2.17 (2A0)
/A5: J5.8 (A5), U2.15 (2A1)
/A6: J5.9 (A6), U2.13 (2A2)
/A7: J5.10 (A7), U2.11 (2A3)
/A8: J5.11 (A8), U3.2 (1A0)
/A9: J5.12 (A9), U3.4 (1A1)
/A10: J5.13 (A10), U3.6 (1A2)
/A11: J5.14 (A11), U3.8 (1A3)
/A12: J5.15 (A12), U3.17 (2A0)
/A13: J5.16 (A13), U3.15 (2A1)
/A14: J5.17 (A14), U3.13 (2A2)
/D0: J5.21 (D0), U4.18 (1Y0)
/D1: J5.22 (D1), U4.16 (1Y1)
/D2: J5.23 (D2), U4.14 (1Y2)
/D3: J5.24 (D3), U4.12 (1Y3)
/D4: J5.25 (D4), U4.3 (2Y0)
/D5: J5.26 (D5), U4.5 (2Y1)
/D6: J5.27 (D6), U4.7 (2Y2)
/D7: J5.28 (D7), U4.9 (2Y3)
/MISO: J2.1, U5.1, U6.18 (PB4)
/MOSI: J2.4, U6.17 (PB3)
/RAMA0: U1.10 (A0), U2.18 (1Y0), U9.2 (O0)
/RAMA1: U1.9 (A1), U2.16 (1Y1), U9.5 (O1)
/RAMA2: U1.8 (A2), U2.14 (1Y2), U9.6 (O2)
/RAMA3: U1.7 (A3), U2.12 (1Y3), U9.9 (O3)
/RAMA4: U1.6 (A4), U2.3 (2Y0), U9.12 (O4)
/RAMA5: U1.5 (A5), U2.5 (2Y1), U9.15 (O5)
/RAMA6: U1.4 (A6), U2.7 (2Y2), U9.16 (O6)
/RAMA7: U1.3 (A7), U2.9 (2Y3), U9.19 (O7)
/RAMA8: U1.25 (A8), U3.18 (1Y0), U7.2 (O0)
/RAMA9: U1.24 (A9), U3.16 (1Y1), U7.5 (O1)
/RAMA10: U1.21 (A10), U3.14 (1Y2), U7.6 (O2)
/RAMA11: U1.23 (A11), U3.12 (1Y3), U7.9 (O3)
/RAMA12: U1.2 (A12), U3.3 (2Y0), U7.12 (O4)
/RAMA13: U1.26 (A13), U3.5 (2Y1), U7.15 (O5)
/RAMA14: U1.1 (A14), U3.7 (2Y2), U7.16 (O6)
/RAMD0: U1.19 (Q7), U4.2 (1A0), U6.23 (PC0), U7.3 (D0), U9.3 (D0)
/RAMD1: U1.18 (Q6), U4.4 (1A1), U6.24 (PC1), U7.4 (D1), U9.4 (D1)
/RAMD2: U1.17 (Q5), U4.6 (1A2), U6.4 (PD2), U7.7 (D2), U9.7 (D2)
/RAMD3: U1.16 (Q4), U4.8 (1A3), U6.5 (PD3), U7.8 (D3), U9.8 (D3)
/RAMD4: U1.15 (Q3), U4.17 (2A0), U6.6 (PD4), U7.13 (D4), U9.13 (D4)
/RAMD5: U1.13 (Q2), U4.15 (2A1), U6.11 (PD5), U7.14 (D5), U9.14 (D5)
/RAMD6: U1.12 (Q1), U4.13 (2A2), U6.12 (PD6), U7.17 (D6), U9.17 (D6)
/RAMD7: U1.11 (Q0), U4.11 (2A3), U6.13 (PD7), U9.18 (D7)
/SCK: J2.3, U5.5, U6.19 (PB5)
GND: C1.2, C2.2, C3.2, C4.2, C5.2, C6.2, C8.2, C9.2, C10.2, C11.2, C12.2, C14.2, C15.2, C16.2, J2.6, J3.A1 (GND), J3.A12 (GND), J3.B1 (GND), J3.B12 (GND), J3.S1 (SHIELD), J5.1 (GND), J5.18 (GND), J5.19 (GND), J5.33 (~ROM), J5.36 (GND), R2.2, R3.2, R4.2, R5.1, U1.14 (GND), U2.10 (GND), U3.10 (GND), U3.11 (2A3), U4.10 (GND), U5.7 (GND), U6.8 (GND), U6.22 (AGND), U7.10 (GND), U7.18 (D7), U8.3 (GND), U9.10 (GND), U10.6 (1A2), U10.8 (1A3), U10.10 (GND), U10.11 (2A3), U10.13 (2A2), U10.15 (2A1), U10.17 (2A0), U10.19 (2OE)
unnamed: J2.5, R1.2, U6.1 (PC6/~RESET)
unnamed: J3.A5 (CC1), R3.1
unnamed: J3.B5 (CC2), R2.1
unnamed: J5.30 (~CS), U10.4 (1A1)
unnamed: J5.29 (~IRQ), U6.28 (PC5)
unnamed: J5.31 (~RD), U10.2 (1A0)
unnamed: J5.34 (~RST), U6.15 (PB1)
unnamed: U1.20 (~CS), U5.6, U5.10
unnamed: U1.22 (~OE), U5.3, U5.9
unnamed: U1.27 (~WE), U6.25 (PC2)
unnamed: U4.1 (1OE), U4.19 (2OE), U5.11
unnamed: U5.8, U5.13
unnamed: C14.1, U6.21 (AREF)
unnamed: U6.14 (PB0), U7.11 (LE)
unnamed: U6.16 (PB2), U9.11 (LE)
unnamed: C16.1, U6.9 (PB6/XTAL1), Y1.2
unnamed: C15.1, U6.10 (PB7/XTAL2), Y1.1
unnamed: U6.26 (PC3), U7.1 (OE), U9.1 (OE)
unnamed: U6.2 (PD0), U8.6 (TXD)
unnamed: U6.3 (PD1), U8.7 (RXD)
unnamed: J3.A6 (D+), J3.B6 (D+), U8.1 (UD+)
unnamed: J3.A7 (D-), J3.B7 (D-), U8.2 (UD-)
unnamed: C1.1, U8.8 (V3)
unnamed: U2.1 (1OE), U2.19 (2OE), U3.1 (1OE), U3.19 (2OE), U5.12, U6.27 (PC4), U10.1 (1OE)
unnamed: R4.1, U5.2, U10.18 (1Y0)
unnamed: R5.2, U5.4, U10.16 (1Y1)
VCC: C2.1, C3.1, C4.1, C5.1, C6.1, C8.1, C9.1, C10.1, C11.1, C12.1, J2.2, J5.2 (VCC), J5.20 (VCC), J5.35 (VCC), R1.1, U1.28 (VCC), U2.20 (VCC), U3.20 (VCC), U4.20 (VCC), U5.14 (VCC), U6.7 (VCC), U6.20 (AVCC), U7.20 (VCC), U8.5 (VCC), U9.20 (VCC), U10.20 (VCC)

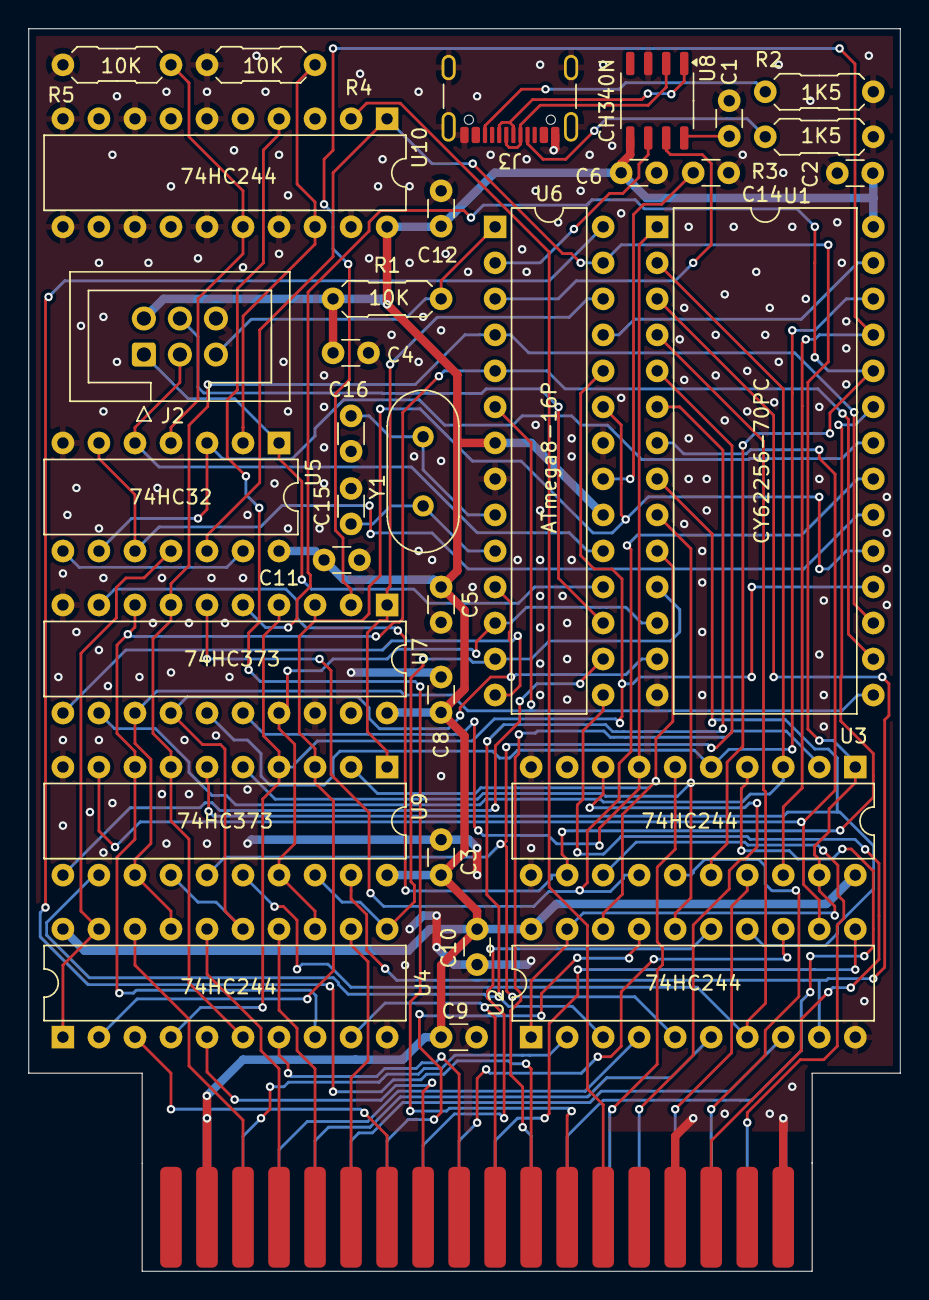
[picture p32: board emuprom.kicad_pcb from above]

Board: 2 copper layers, 61.5 x 87.6 mm, 33 parts (0 on the bottom side), 77 nets.

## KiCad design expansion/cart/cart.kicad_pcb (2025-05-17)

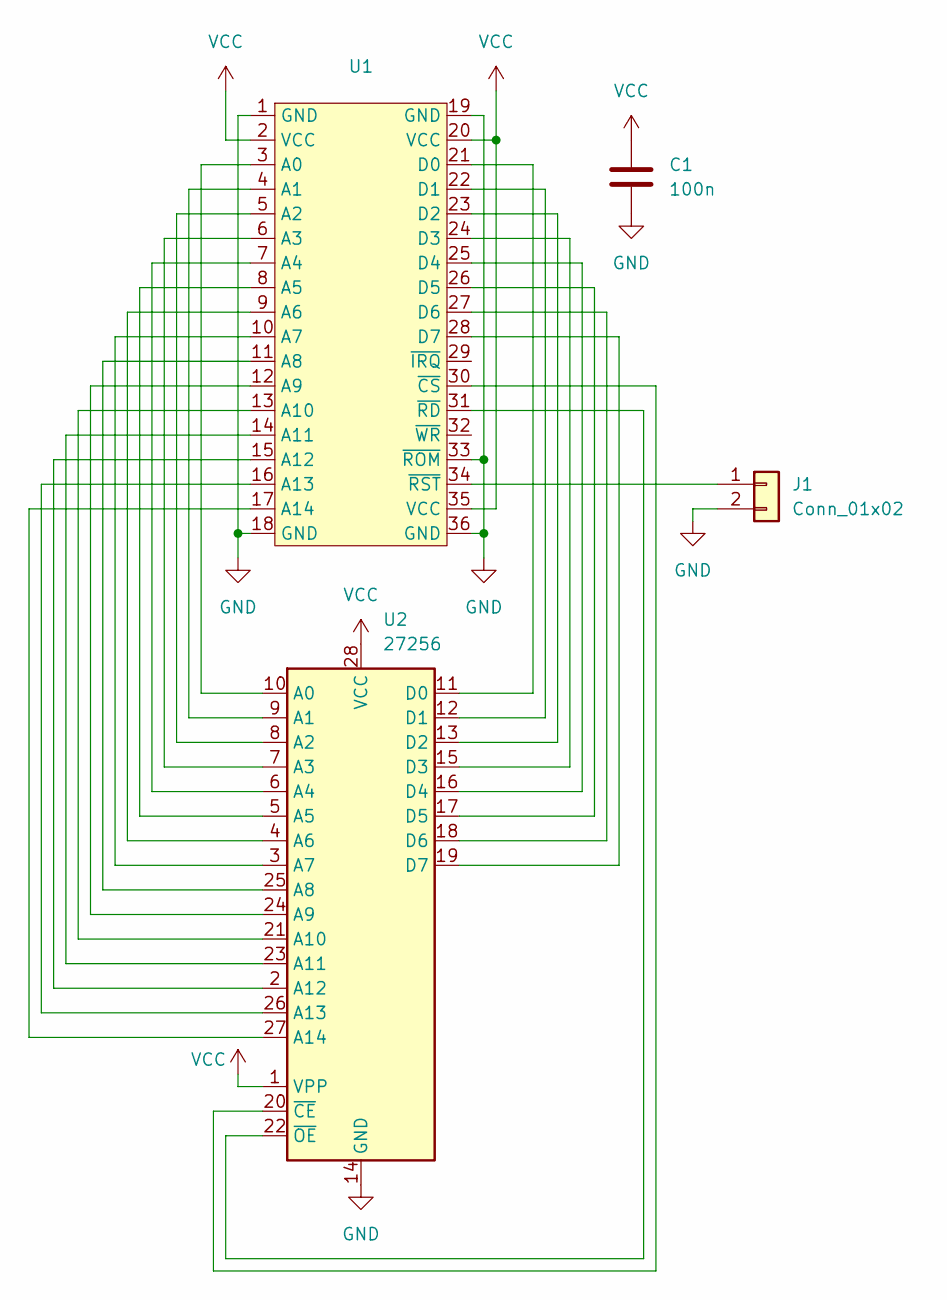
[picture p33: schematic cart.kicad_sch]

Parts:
C1: 100n; C_Disc_D3.4mm_W2.1mm_P2.50mm
J1: Conn_01x02; PinHeader_1x02_P2.54mm_Vertical
U1: CART_FELLA_38
U2: 27256; DIP-28_W15.24mm

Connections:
GND: C1.2, J1.2, U1.1 (GND), U1.18 (GND), U1.19 (GND), U1.33 (~ROM), U1.36 (GND), U2.14 (GND)
unnamed: J1.1, U1.34 (~RST)
unnamed: U1.3 (A0), U2.10 (A0)
unnamed: U1.4 (A1), U2.9 (A1)
unnamed: U1.5 (A2), U2.8 (A2)
unnamed: U1.6 (A3), U2.7 (A3)
unnamed: U1.7 (A4), U2.6 (A4)
unnamed: U1.8 (A5), U2.5 (A5)
unnamed: U1.9 (A6), U2.4 (A6)
unnamed: U1.10 (A7), U2.3 (A7)
unnamed: U1.11 (A8), U2.25 (A8)
unnamed: U1.12 (A9), U2.24 (A9)
unnamed: U1.13 (A10), U2.21 (A10)
unnamed: U1.14 (A11), U2.23 (A11)
unnamed: U1.15 (A12), U2.2 (A12)
unnamed: U1.16 (A13), U2.26 (A13)
unnamed: U1.17 (A14), U2.27 (A14)
unnamed: U1.21 (D0), U2.11 (D0)
unnamed: U1.22 (D1), U2.12 (D1)
unnamed: U1.23 (D2), U2.13 (D2)
unnamed: U1.24 (D3), U2.15 (D3)
unnamed: U1.25 (D4), U2.16 (D4)
unnamed: U1.26 (D5), U2.17 (D5)
unnamed: U1.27 (D6), U2.18 (D6)
unnamed: U1.28 (D7), U2.19 (D7)
unnamed: U1.30 (~CS), U2.20 (~CE)
unnamed: U1.31 (~RD), U2.22 (~OE)
VCC: C1.1, U1.2 (VCC), U1.20 (VCC), U1.35 (VCC), U2.1 (VPP), U2.28 (VCC)


Board: 2 copper layers, 47.2 x 29.2 mm, 4 parts (0 on the bottom side), 28 nets.

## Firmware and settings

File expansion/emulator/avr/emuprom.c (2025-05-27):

/*
 * PORTD[7..2] - PORTC[1..0]: data
 *
 * PORTB0: Latch Enable high
 * PORTB1: /RESET
 * PORTB2: Latch Enable low
 *
 * PORTB4: /OE
 * PORTB5: /CS
 *
 * PORTC2: /WE
 * PORTC3: Claim by AVR (active low)
 * PORTC4: Claim by 6502 (active low)
 * PORTC5: /IRQ
 *
 * PORTD0: RX
 * PORTD1: TX
 */

#include <avr/io.h>
#include <avr/interrupt.h>
#include <util/delay.h>

#include "uart/uart.h"
#include "md5/md5.h"

#include <stdint.h>
#include <stdbool.h>
#include <stdio.h>

static inline void nop(void)
{
	__asm__ volatile ("\tnop;");
}

#define SET(port, pin) ((port) |= (1 << (pin)))

#define CLEAR(port, pin) ((port) &= ~(1 << (pin)))

#define TOGGLE_HIGH(port, pin) \
	do { \
		nop(); \
		SET(port, pin); \
		nop(); \
		CLEAR(port, pin); \
		nop(); \
	} while (0)

#define TOGGLE_LOW(port, pin) \
	do { \
		nop(); \
		CLEAR(port, pin); \
		nop(); \
		SET(port, pin); \
		nop(); \
	} while (0)

static void claim(void)
{
	/* Reset target */
	CLEAR(PORTB, 1);
	SET(DDRB, 1);

	/* Inactivate control signals */
	SET(PORTC, 2);
	SET(PORTB, 4);
	SET(PORTB, 5);

	/* Claim bus */
	SET(PORTC, 4);
	CLEAR(PORTC, 3);

	/* Set data bus as output */
	DDRD |= 0xfc;
	DDRC |= 0x3;
}

static void release(void)
{
	/* Inactivate control signals */
	SET(PORTC, 2);
	SET(PORTB, 4);
	SET(PORTB, 5);

	/* High-Z data bus */
	DDRD &= ~0xfc;
	DDRC &= ~0x3;

	/* Release bus */
	SET(PORTC, 3);
	CLEAR(PORTC, 4);

	/* Allow-gate /CS and /OE */
	CLEAR(PORTB, 4);
	CLEAR(PORTB, 5);

	/* Release target reset */
	CLEAR(DDRB, 1);
	SET(PORTB, 1);
}

static void setData(uint8_t data)
{
	uint8_t t = PORTC & ~(0x3);
	PORTC = t | (data & 0x3);
	t = PORTD & ~(0xfc);
	PORTD = t | (data & 0xfc);
	nop();
}

static uint8_t getData(void)
{
	uint8_t d = PINC & 0x3;
	d |= PIND & 0xfc;
	return d;
}

static void setAddr(uint16_t addr)
{
	setData(addr & 0xff);
	nop();
	TOGGLE_HIGH(PORTB, 2);
	nop();
	setData(addr >> 8);
	nop();
	TOGGLE_HIGH(PORTB, 0);
	nop();
}

static void write(uint16_t addr, uint8_t data)
{
	setAddr(addr);
	setData(data);
	nop();

	/* Activate /CS */
	CLEAR(PORTB, 5);
	nop();

	/* Write */
	TOGGLE_LOW(PORTC, 2);
	nop();

	/* Inactivate /CS */
	SET(PORTB, 5);
}

static uint8_t read(uint16_t addr)
{
	uint8_t ret = 0xff;

	setAddr(addr);

	/* Data as input */
	DDRC &= ~0x3;
	DDRD &= ~0xfc;
	PORTC |= 0x3;
	PORTD |= 0xfc;

	nop();
	nop();
	nop();

	/* Activate /CS and /OE */
	CLEAR(PORTB, 5);
	CLEAR(PORTB, 4);

	nop();
	nop();
	nop();

	ret = getData();

	/* Inactivate /CS and /OE */
	SET(PORTB, 4);
	SET(PORTB, 5);

	nop();

	/* Bus back as output */
	DDRC |= 0x3;
	DDRD |= 0xfc;

	return ret;
}

static int memtest_fail(uint16_t addr, uint8_t expected, uint8_t got)
{
	char buff[40];
	sprintf(buff, "Fail @0x%04x (expected 0x%02x, got 0x%02x)\n",
		addr, expected, got);
	uart_puts(buff);
	return -1;
}

static void fill(uint8_t val)
{
	for (uint16_t addr = 0; addr < (32u * 1024); ++addr)
		write(addr, val);
}

static int test(uint8_t expected)
{
	for (uint16_t addr = 0; addr < (32u * 1024); ++addr) {
		uint8_t readback = read(addr);
		if (readback != expected) {
			return memtest_fail(addr, expected, readback);
		}
	}
	
	return 0;
}

static int memtest(void)
{
	fill(0);
	if (test(0)) return -1;
	fill(0x55);
	if (test(0x55)) return -1;
	fill(0xaa);
	if (test(0xaa)) return -1;
	fill(0xff);
	if (test(0xff)) return -1;

	return 0;
}

static void dump(uint16_t *addr)
{
	char buff[16];
	uint16_t i, j;

	for (i = 0; i < 256 && i + *addr < 32u * 1024; i += 16) {
		sprintf(buff, "%04x: ", i + *addr);
		uart_puts(buff);
		for (j = 0; j < 16; ++j) {
			uint8_t data = read(*addr + i + j);
			sprintf(buff, "%02x%s", data, (j != 15) ? ", " : "");
			uart_puts(buff);
		}
		uart_putc('\n');
	}
	
	*addr += i;
}

static void help(void)
{
	uart_puts("EPROM Emulator\nA.K. 2024\nCommands:\n");
	uart_puts("\t? - this help\n");
	uart_puts("\t! - claim bus, memory edit, assert /RST\n");
	uart_puts("\t. - release bus, deassert /RST\n");
	uart_puts("\t@ - set address mode\n");
	uart_puts("\t# - set data mode\n");
	uart_puts("\t= - dump 256 bytes @addres\n");
	uart_puts("\tt - memory test\n");
	uart_puts("\t+ - echo on\n");
	uart_puts("\t- - echo off\n");
	uart_puts("\tm - calculate md5 sum\n");
	uart_puts("\ts - clear memory (all 0xff)\n");
	uart_puts("\tr - reset target (pulse /RST)\n");
	uart_puts("\tq - send IRQ (pulse /IRQ)\n");
}

static void md5(void)
{
	MD5Context ctx;
	uint8_t buff[64];

	md5Init(&ctx);

	for (uint16_t i = 0; i < 32u * 1024; i += sizeof(buff)) {
		for (uint16_t j = 0; j < sizeof(buff); ++j) {
			buff[j] = read(i + j);
		}
		md5Update(&ctx, buff, sizeof(buff));
	}

	md5Finalize(&ctx);
	
	uart_puts("md5: ");
	for (uint8_t i = 0; i < sizeof(ctx.digest); ++i) {
		sprintf((char *)buff, "%02x", ctx.digest[i]);
		uart_puts((char *)buff);
	}
	uart_putc('\n');
}

static int parse(char c)
{
	static uint16_t addr;
	static uint8_t data;
	static uint8_t cnt;
	static enum { mode_addr, mode_data } mode = mode_data;
	static bool claimed = true;
	static int echoOff = 0;
	uint8_t val;
	int err;

	if ((c >= '0') && (c <= '9')) {
		val = c - '0';
	}
	else if ((c >= 'a') && (c <= 'f')) {
		val = c + 10 - 'a';
	}
	else if ((c >= 'A') && (c <= 'F')) {
		val = c + 10 - 'A';
	}
	else {
		switch (c) {
			case '!':
				claim();
				claimed = true;
				break;

			case '@':
				mode = mode_addr;
				cnt = 0;
				break;

			case '#':
				mode = mode_data;
				cnt = 0;
				break;

			case '.':
				release();
				claimed = false;
				break;

			case '=':
				if (claimed)
					dump(&addr);
				return -1; /* Supress echo */

			case '+':
				echoOff = 0;
				break;

			case '-':
				echoOff = 1;
				break;

			case 's':
				if (!claimed)
					return -1;
				fill(0xff);
				break;
				
			case 'r':
				CLEAR(PORTB, 1);
				SET(DDRB, 1);
				_delay_ms(100);
				CLEAR(DDRB, 1);
				SET(PORTB, 1);
				break;

			case 'q':
				CLEAR(PORTC, 5);
				SET(DDRC, 5);
				nop();
				CLEAR(DDRC, 5);
				break;

			case 'm':
				if (claimed)
					md5();
				return -1; /* Supress echo */

			case '?':
				help();
				return -1; /* Supress echo */

			case 't':
				err = claimed ? memtest() : -1;
				if (!err) {
					uart_puts("Memory OK\n");
				}
				return -1; /* Supress echo */

			default:
				return -1;
		}

		return echoOff;
	}

	if (mode == mode_addr) {
		addr = (addr << 4) | val;
	}
	else {
		data = (data << 4) | val;
		if (++cnt > 1) {
			if (claimed)
				write(addr, data);
			addr++;
			cnt = 0;
		}
	}

	return echoOff;
}

int main(void)
{
	DDRB = (1 << 5) | (1 << 4) | (1 << 2) | 1;
	DDRC = (1 << 4) | (1 << 3) | (1 << 2);
	DDRD = (1 << 1);

	PORTB = (1 << 5) | (1 << 4) | (1 << 2) | 1;
	PORTC = (1 << 5) | (1 << 4) | (1 << 3) | (1 << 2);
	PORTD = 0;
	
	claim();

	uart_init(7); /* 115200 */
	sei();
	
	fill(0xff);
	help();

	while (1) {
		int rx;
		do {
			rx = uart_getc();
		} while ((rx & ~0xff) != 0);
		
		if (!parse(rx & 0xff)) {
			uart_putc(rx & 0xff);
		}
	}

	return 0;
}

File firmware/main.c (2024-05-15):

/* FellaPC Firmaware
 * main
 * Copyright: Aleksander Kaminski, 2024
 * See LICENSE.md
 */

#include <stdio.h>
#include <stdlib.h>

#include "system.h"
#include "vga.h"
#include "keyboard.h"
#include "tty.h"
#include "ualloc/ualloc.h"
#include "cmd.h"

static const char prompt[] = "Ready\n";
static char cmd[VGA_COLS + 1];

const char *welcome[] = {
	"CLEAR",
	"PRINT\"FellaPC " VERSION "\"",
	"PRINT\"github.com/agkaminski/FellaPC\"",
	"PRINT\"Copyright A.K. 2024\"",
	"PRINT\"BASIC\";FRE;\"bytes free.\"",
	"NEW"
};

int main(void)
{
	int8_t err = 0, i;
	char buff[16] = "error ";

	system_init();

	for (i = 0; i < sizeof(welcome) / sizeof(*welcome); ++i) {
		cmd_parse(welcome[i]);
	}

	while (1) {
		if (err < 0) {
			itoa(-err, buff + 6, 10);
			vga_puts(buff);
			vga_putc('\n');
		}
		else if (err == 0) {
			vga_putc('\n');
			vga_puts(prompt);
		}

		do {
			vga_vsync();
			err = tty_update(cmd);
		} while (err <= 0);

		err = cmd_parse(cmd);
	}

	return 0;
}

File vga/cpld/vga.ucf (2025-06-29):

#PACE: Start of Constraints generated by PACE

#PACE: Start of PACE I/O Pin Assignments
NET "blank"  LOC = "P3"  ; 
NET "vblank_n"  LOC = "P19"  ; 
NET "col<3>"  LOC = "P18"  ; 
NET "col<4>"  LOC = "P14"  ; 
NET "col<5>"  LOC = "P13"  ; 
NET "col<6>"  LOC = "P12"  ; 
NET "col<7>"  LOC = "P11"  ; 
NET "col<8>"  LOC = "P9"  ; 
NET "col<9>"  LOC = "P8"  ; 
NET "hsync"  LOC = "P2"  ; 
NET "oe_n"  LOC = "P37"  ; 
NET "pclk"  LOC = "P5"  ; 
NET "row<0>"  LOC = "P36"  ; 
NET "row<1>"  LOC = "P35"  ; 
NET "row<2>"  LOC = "P34"  ; 
NET "row<3>"  LOC = "P33"  ; 
NET "row<4>"  LOC = "P29"  ; 
NET "row<5>"  LOC = "P28"  ; 
NET "row<6>"  LOC = "P27"  ; 
NET "row<7>"  LOC = "P26"  ; 
NET "row<8>"  LOC = "P25"  ; 
NET "rst_n"  LOC = "P39"  ; 
NET "shload_n"  LOC = "P4"  ; 
NET "vsync"  LOC = "P1"  ; 
NET "scroll<0>"  LOC = "P20"  ;
NET "scroll<1>"  LOC = "P22"  ;
NET "scroll<2>"  LOC = "P43"  ;
NET "scroll<3>"  LOC = "P44"  ;
NET "scroll<4>"  LOC = "P24"  ;
NET "scroll<5>"  LOC = "P38"  ;

#PACE: Start of PACE Area Constraints

#PACE: Start of PACE Prohibit Constraints

#PACE: End of Constraints generated by PACE

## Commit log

2024-03-17 Initial import
    [clock.kicad_sch, cpu.kicad_sch, fella.kicad_pcb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]
2024-03-17 Add keyboard connector
    [cpu.kicad_sch, fella.kicad_sch, keyboard.kicad_sch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]
2024-03-17 Add user IO and USB
    [clock.kicad_sch, cpu.kicad_sch, fella.kicad_pcb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]
2024-03-17 Add expansion slot
    [cpu.kicad_sch, expansion.kicad_sch, fella.kicad_pcb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]
2024-03-17 Add caps and make initial placement
    [clock.kicad_sch, cpu.kicad_sch, expansion.kicad_sch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]
2024-03-18 Bugfixes, start routing
    [cpu.kicad_sch, expansion.kicad_sch, fella.kicad_pcb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]
2024-03-18 Board outline
    [fella.kicad_sch]
2024-03-19 Finished routing, HW prototype ready
    [bom.csv, cpu.kicad_sch, designators.csv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]
2024-03-19 Add preliminary PCB visualisation
2024-03-19 Add pdf schematic
2024-03-20 Add cc65 BSP and FW build
    [fellapc.cfg]
2024-03-20 Move schematic to the main dir
2024-03-22 Add HW test code stub
    [fellapc.cfg]
2024-04-06 Move FW to firmware/ dir, add dram, i2c and vga code
    [fellapc.cfg]
2024-04-28 fw: Debug and fix keyboard code
    [main.c]
2024-04-29 fw: Add VIA gpio driver and VGA rom selection
2024-04-30 hw: Start work on rev B
    Changelog:
    - fixed IO address decoder (removed /PH2 gating),
    - added missing reset circuit capacitor,
    - added hardware VGA scrolling,
    - removed VGA column register, replaced with address bus,
    - fixed values of R5 and R6.
    [bom.csv, clock.kicad_sch, cpu.kicad_sch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]
2024-04-30 Add mechanical drawing and case 3D models
    [case.FCStd, case.stl, frame.FCStd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]
2024-04-30 fw: Implement insert typing mode
2024-04-30 fw: Fix inserting
2024-04-30 hw: Finished rev B
    - added fuse for the expansion port,
    - added silkscreen symbols.
    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
    [bom.csv, clock.kicad_sch, designators.csv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]
2024-05-01 fw: print non-negative errors
    [main.c]
2024-05-01 fw: fix insert when line's full
2024-05-02 fw: print real without exponent when possible
2024-05-04 fw: increase stack size
    [fellapc.cfg]
2024-05-04 fw: add print implementation
2024-05-04 fw: reduce the heap, increase the stack size
    [fellapc.cfg]
2024-05-09 fw: fix multi-argument print with comas
2024-05-12 fw: Use all available RAM for heap
    [fellapc.cfg]
2024-05-19 fw: move i2c code to asm, not tested
2024-08-17 fw: Working i2c save/restore
2025-05-05 New case design
    [body.stl, bottom.stl, case.stl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]
2025-05-05 case: fix no room for keyboard connector pins
    [keyboard.stl]
2025-05-05 case: increase bottom panel width
    Needed to:
    - clear screws that mount the motherboard,
    - match 25 mm main case screws
    [bottom.stl]
2025-05-05 case: update README
2025-05-05 case: increase body height, make relief for I/O ports
    [body.stl]
2025-05-14 Add mini case
    [mini-Body.stl, mini-Bottom.stl]
2025-05-14 mini case: increase sidewall thickness
    [mini-Body.stl, mini-Bottom.stl]
2025-05-14 minicase: Increase height by 1mm, fix expansion port
    [mini-Body.stl]
2025-05-17 hw: revision C
    Major changes:
    - ROM space has been extended from 16 KiB to 32 KiB
    - dynamic RAM option has been removed
    - RAM size has been reduced from 32 KiB to 24 KiB
    - expansion slot now replaces internal ROM, does not
    have dedicated memory space anymore
    - place all I/O within a compactish 8 KiB
    - move PH2 gating to /RD and /WR signals
    - PCB redo (mechanicaly compatible)
    [clock.kicad_sch, cpu.kicad_sch, expansion.kicad_sch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]
2025-05-17 hw: add ROM cart
    [cart.kicad_pcb, cart.kicad_sch]
2025-05-17 hw: make the PCB 2 layer instead of 4
2025-05-17 hw: add rev C production files, remove rev A
    [bom.csv, clock.kicad_sch, cpu.kicad_sch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]
2025-05-17 Adapt the code to the changed memory map
    [fellapc.cfg]
2025-05-17 Update README and schematic
2025-05-17 Update PCB image
2025-05-17 Add ROM cart production files
    [bom.csv, designators.csv, positions.csv]
2025-05-18 Add debugger project (FW TODO)
    [bom.csv, designators.csv, emuprom.kicad_pcb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]
2025-05-18 emulator: Add crystal value to the schematic
    [emuprom.kicad_sch]
2025-05-18 emulator: Add schematic PDF
2025-05-27 expansion/emulator: Fix ROM emulator FW after testing
    [emuprom.c]
2025-06-29 vga/cpld: fix missing vblank_n constraint
    [vga.ucf]
2025-08-04 hw: rev D - replace DB25 connector footprint with available one
    [bom.csv, clock.kicad_sch, cpu.kicad_sch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]
